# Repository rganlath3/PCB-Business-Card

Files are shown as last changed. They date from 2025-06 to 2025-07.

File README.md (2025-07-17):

# PCB Business Card
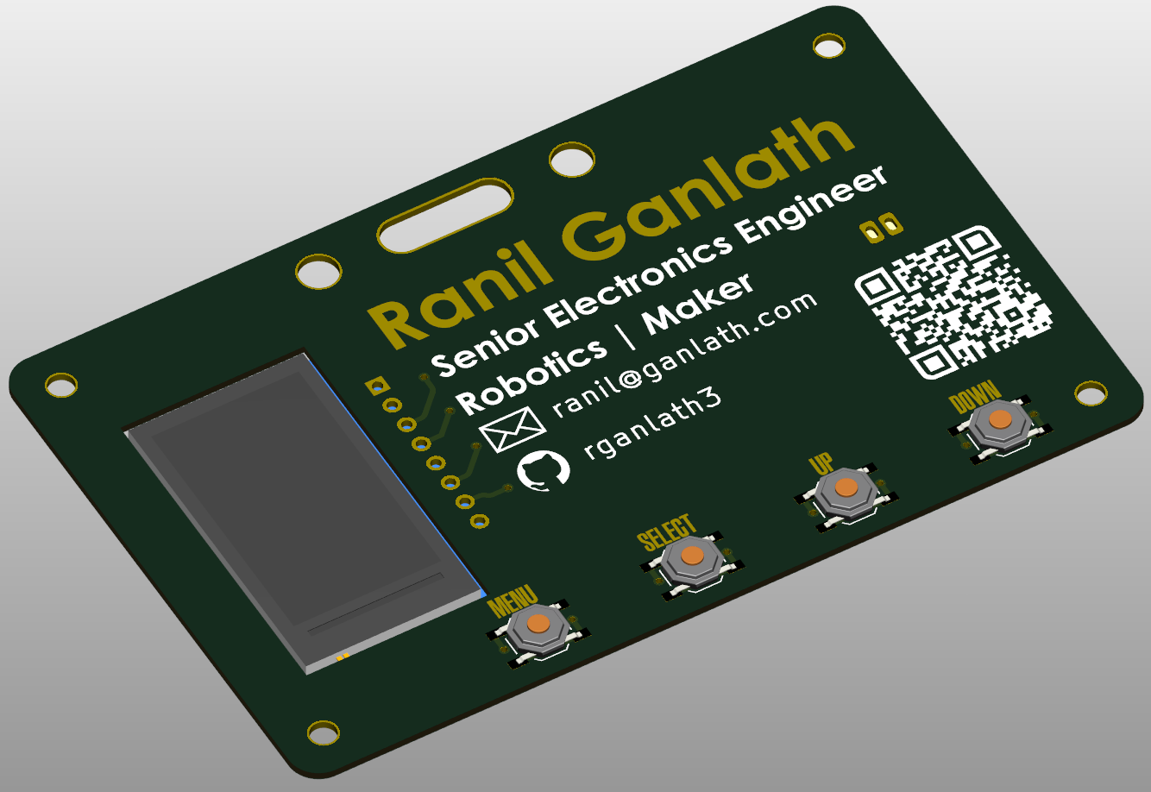
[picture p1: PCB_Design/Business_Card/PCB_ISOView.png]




[]()

<!-- ABOUT -->
## About The Project
A business card with embedded IPS display, SMD pushbuttons, and a XIAO nRF5240 Sense designed to run off a slim LiPo Battery.
The goal of this PCB is to create an artistic business card for conventions, maker spaces, and other social events that stands out either assembled or unassembled for portability.

<!-- REQUIREMENTS -->
### Design Tools & Requirements

#### Software Requirements
- VS Code / Arduino (Programming IDE)
- Autodesk Fusion360 (Free CAD Software)
- KiCAD 9.0 (Open Source PCB Design Software)
- Ultimaker Cura (Free 3D Slicing Software)
- QR Code Generator

#### Bill of Materials
- Custom PCBs
- MCU: XIAO nRF5240 Sense
- Low Profile SMD Momentary Pushbutton: TL3342
- LIPO Connector
- LIPO Battery
- 1.14" 135x240 RGB IPS LCD SPI Display with ST7789V driver IC.

<!-- POWER -->
### Component Power Draw
- XIAO nRF5240 Sense:
- IPS Display:
- Total:
- With Safety Factor (x1.25):
- Recommended Lipo: 
- Estimated Battery Life:

<!-- PCB Design -->
### PCB Design
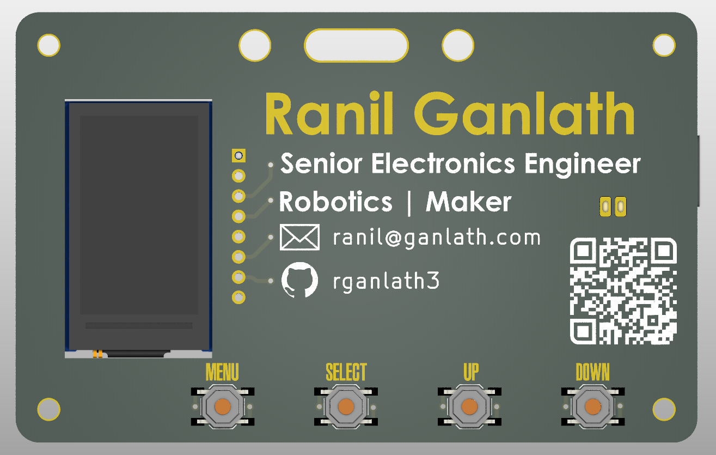
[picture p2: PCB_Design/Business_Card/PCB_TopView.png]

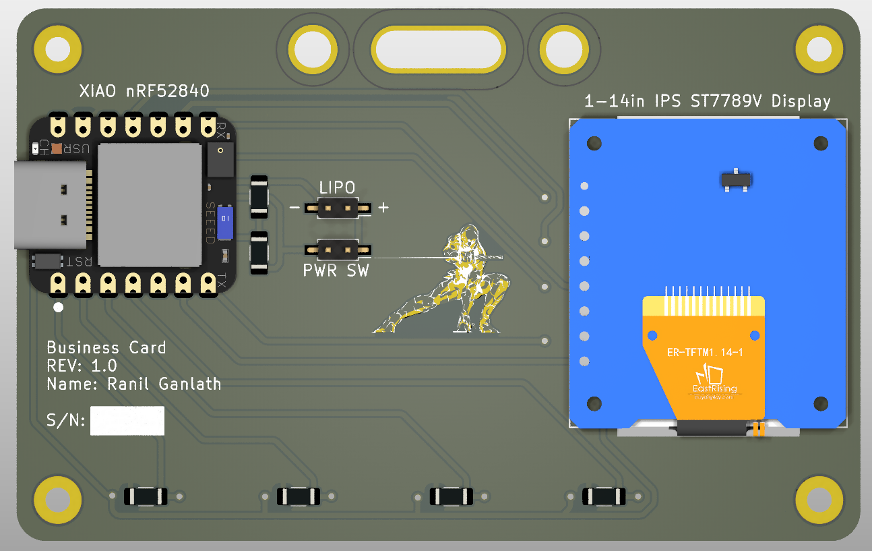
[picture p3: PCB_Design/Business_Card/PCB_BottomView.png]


This PCB is used to interface a XIAO nRF5240 Sense with the following components:
- SMD Pushbuttons
- IPS Display
- Power Source (Lipo Battery)

I did some research on artistic designs and found people using soldermask as a visual aesthetic. When the board is finished with ENIG, it produces a protected and nice gold finish.
For the board thickness I went with 0.8mm. (Typical board is 1.6mm). For future revisions, I may make the board even thinner.
The end goal is not use a breakout board and to simply have the nRF5240 or another board like the ESP32-S3 bare chip used along with battery charging and microphone circuits to reduce the physical space taken up. 

<!-- Software -->
### Software Design
With 4x buttons available along with a microphone input, a variety of things can be displayed on the screen.
I wanted to incorporate a menu system so I can toggle between different modes such as a battery readout display, static image display such as for a QR code, a looping GIF display, a sound reactive display mode, and a control mode to set ambient audio input levels. The limitation of all of this is the amount of flash memory on the XIAO nRF5240. For future revisions, I can incorporate a microSD card.

#### Menu Display
- Call
    - Snake
    - Campbell
    - Naomi
    - Miller
    - Liquid
    - Otacon
    - Sniper Wolf
    - Meryl
    - Mei Ling
    - Nastasha
    - Dt
- Incoming Call
- Animated
    - Snake
    - Campbell
    - Naomi
    - Miller
    - Otacon
    - Sniper Wolf
    - Meryl
    - Mei Ling
    - Nastasha
- Settings
    - Brightness
    - Restart System
- QR
    - QR code for this project
    - QR code for my LinkedIn
    - QR code for my github
- Games
    - TBD
- Sleep

#### Battery Readout Display
TBD

#### Static Image Display
TBD

#### Looping GIF Display
TBD

#### Sound Reactive Display
TBD

#### Ambient Audio Config Display
TBD

#### Game Display
TBD

<!-- CONTRIBUTING -->
## Contributing & Donations

Any donation helps to support parts for future open source projects!
[Buy Me a Coffee ☕](https://www.buymeacoffee.com/rganlath)

Contributions are what make the open source community such an amazing place to learn, inspire, and create. Any contributions you make are **greatly appreciated**.

If you have a suggestion that would make this better, please fork the repo and create a pull request. You can also simply open an issue with the tag "enhancement".
Don't forget to give the project a star! Thanks again!

<!-- LICENSE -->
## License
The contents of this project itself is licensed under CERN-OHL-S-2.0 and the underlying source code is licensed under GNU GPLv3. Both of these licenses require attribution.

<!-- SPECIAL THANKS -->
## Special Thanks
Special thanks to the following creators' github repos for inspiration and techniques used in this project:
- River Wang: https://github.com/urfdvw/cardtuber
- Anythony Kouttron: https://salvagedcircuitry.com/pcb-business-card.html

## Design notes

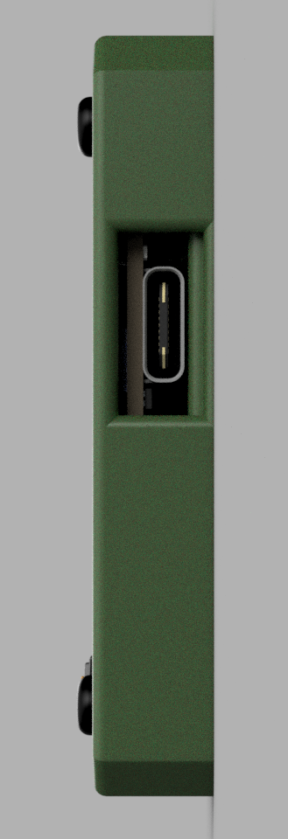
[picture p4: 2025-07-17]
Visual_Assetts/Side View.png

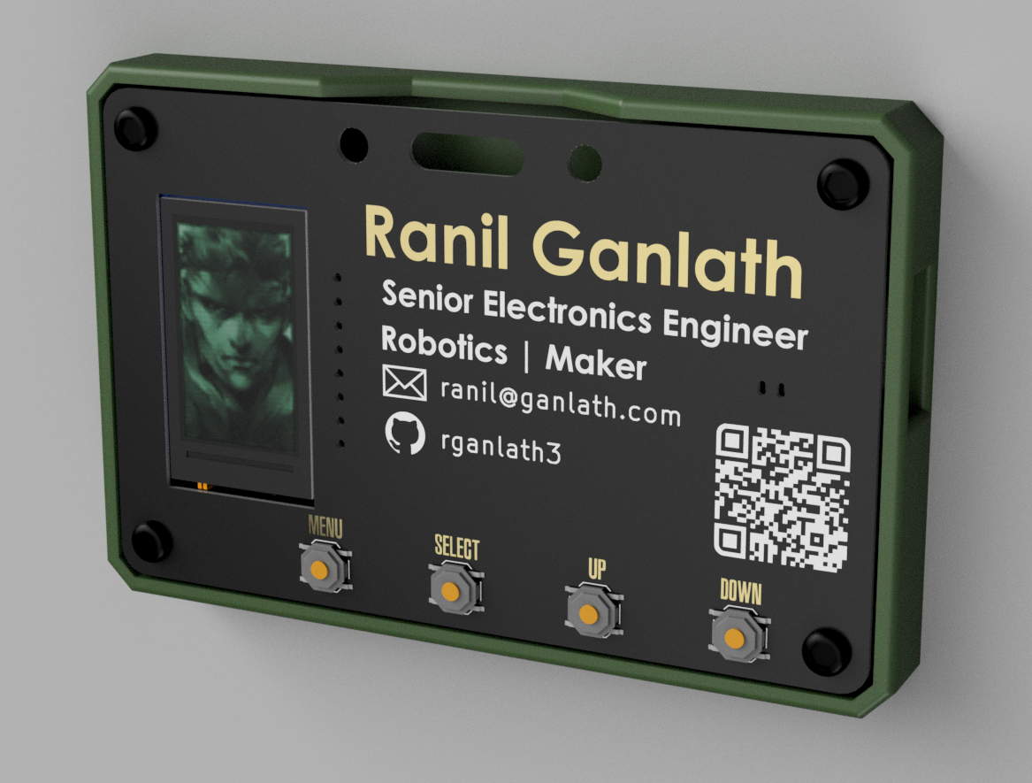
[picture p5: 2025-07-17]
Visual_Assetts/MK1 Render Iso View.png

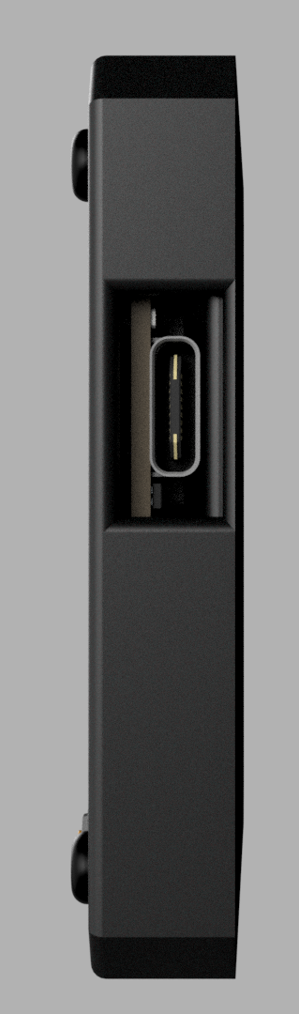
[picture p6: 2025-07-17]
Visual_Assetts/Side View2.png

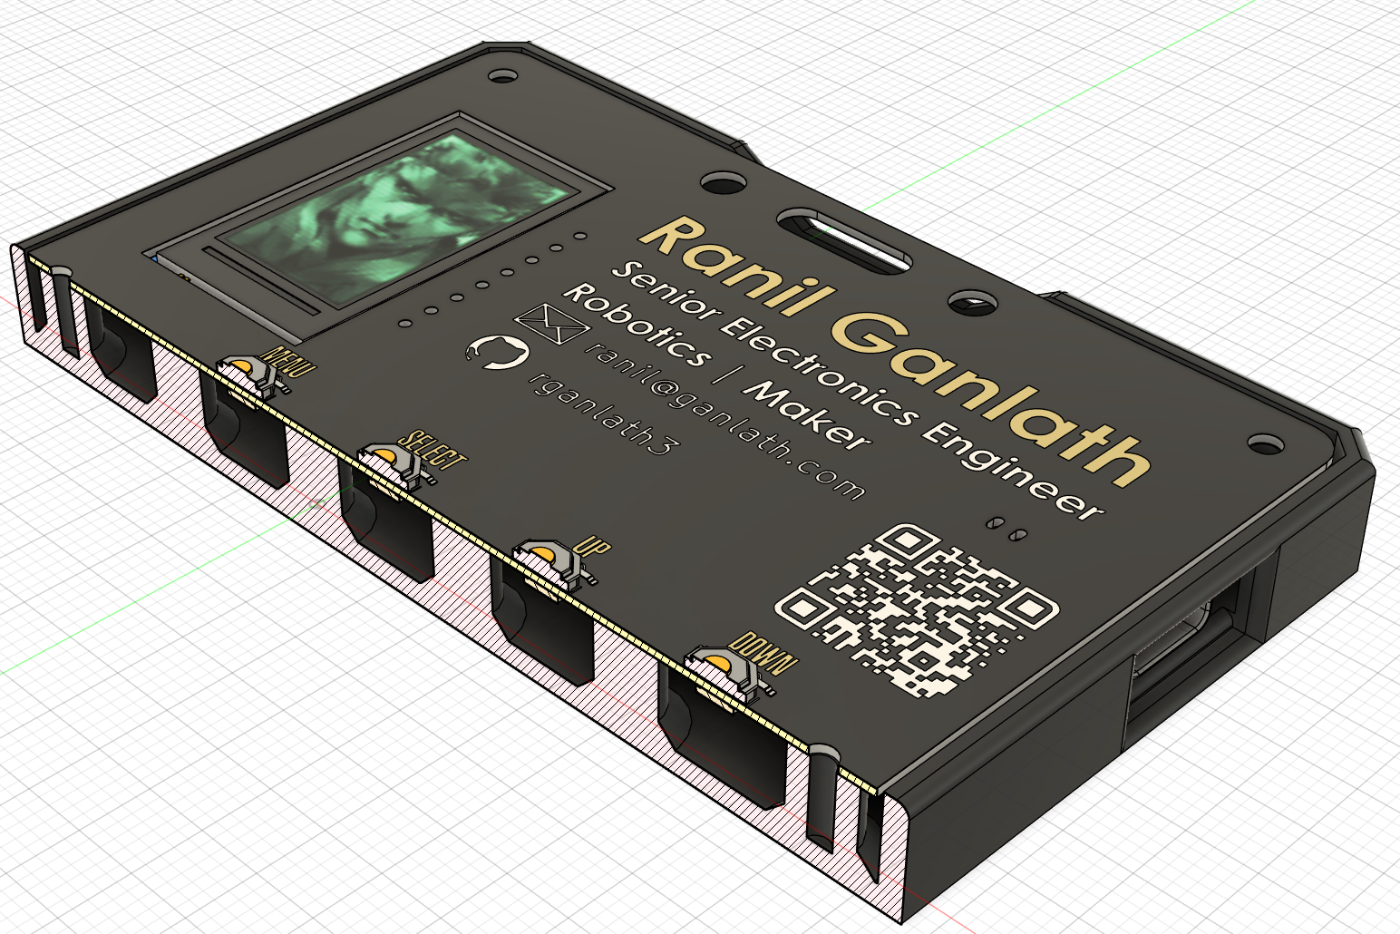
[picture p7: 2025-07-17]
Visual_Assetts/SectionalAnalysis.png

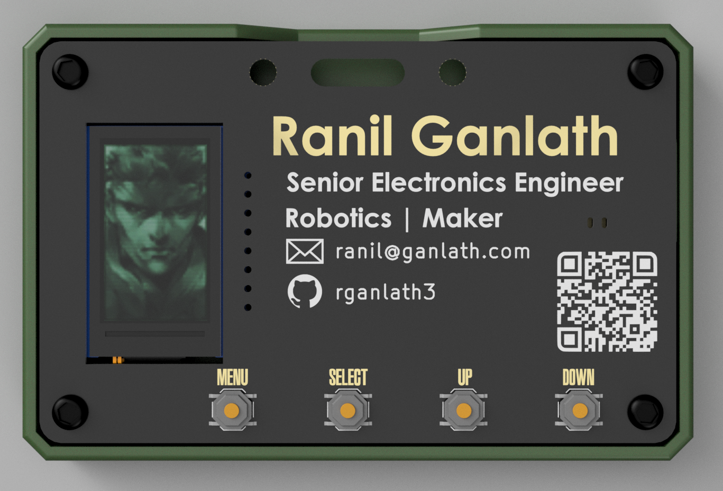
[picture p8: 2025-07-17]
Visual_Assetts/MK1 Render Front View.png

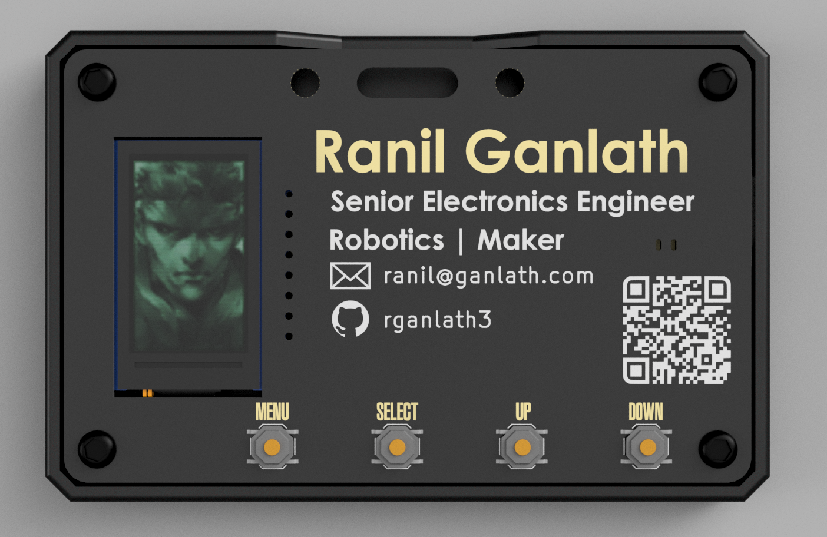
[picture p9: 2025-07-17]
Visual_Assetts/MK1 Render Front View2.png

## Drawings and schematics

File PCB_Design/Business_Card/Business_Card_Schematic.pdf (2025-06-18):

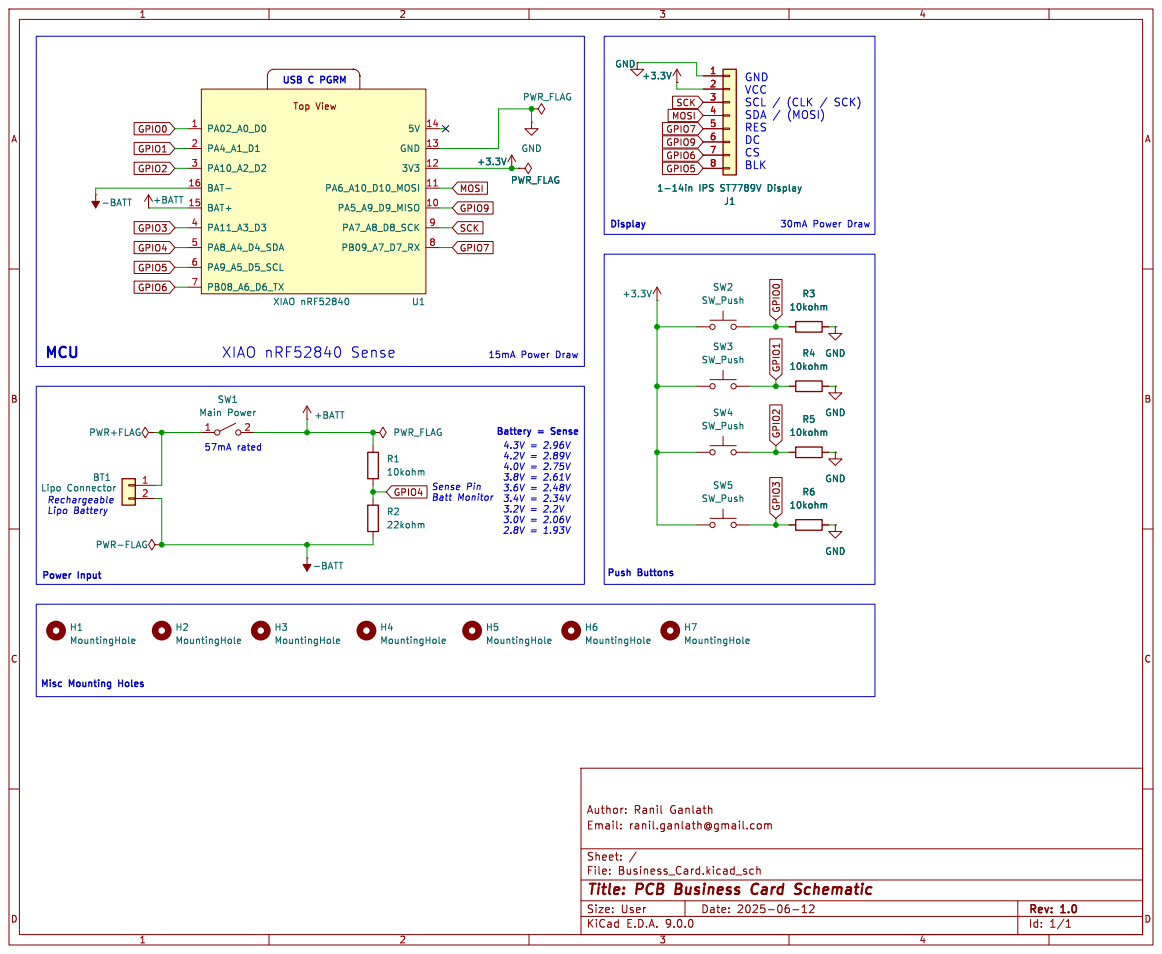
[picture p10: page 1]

VCC
SCL / (CLK / SCK) SDA / (MOSI) RES DC

Id: 1/1 Title: PCB Business Card Schematic

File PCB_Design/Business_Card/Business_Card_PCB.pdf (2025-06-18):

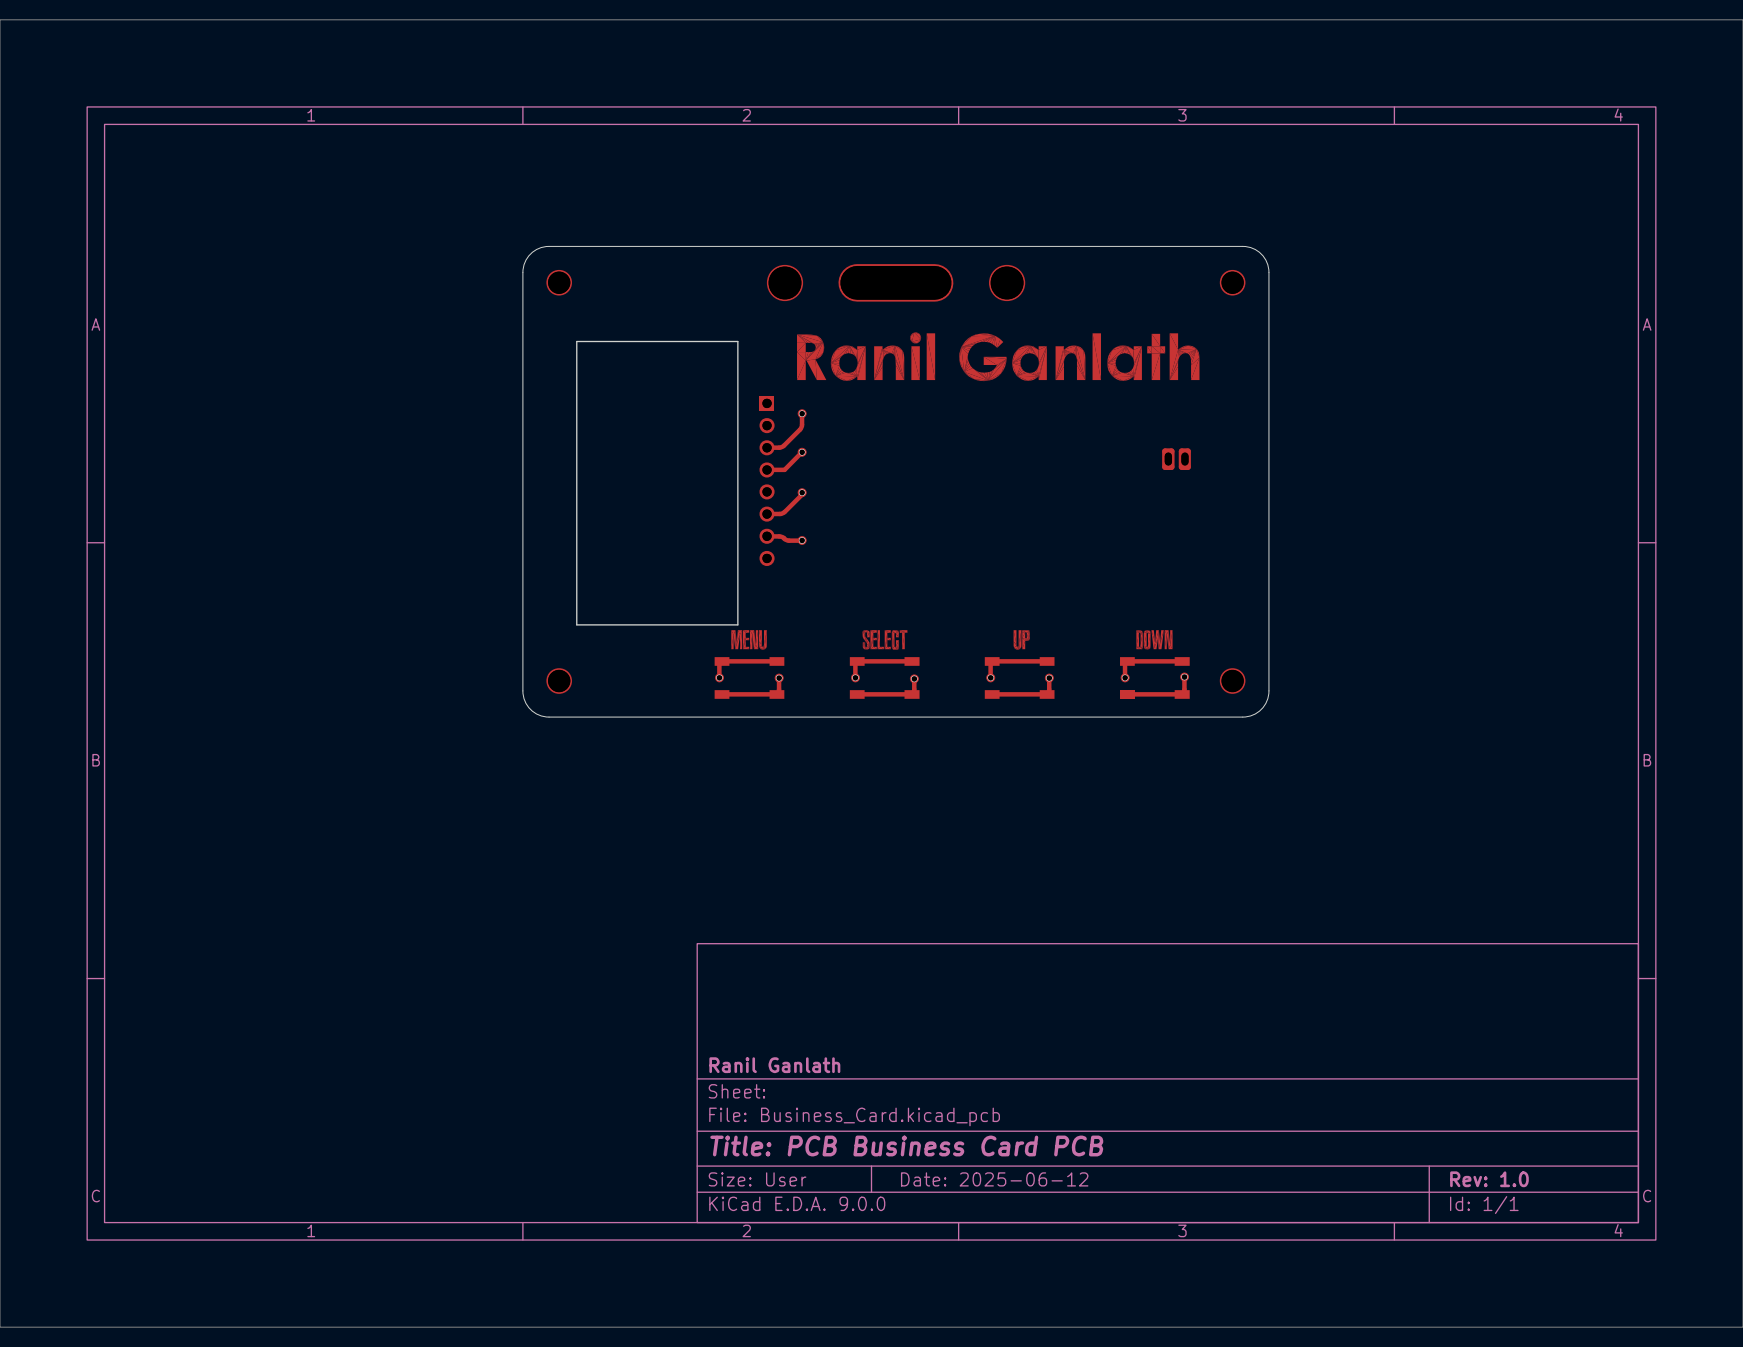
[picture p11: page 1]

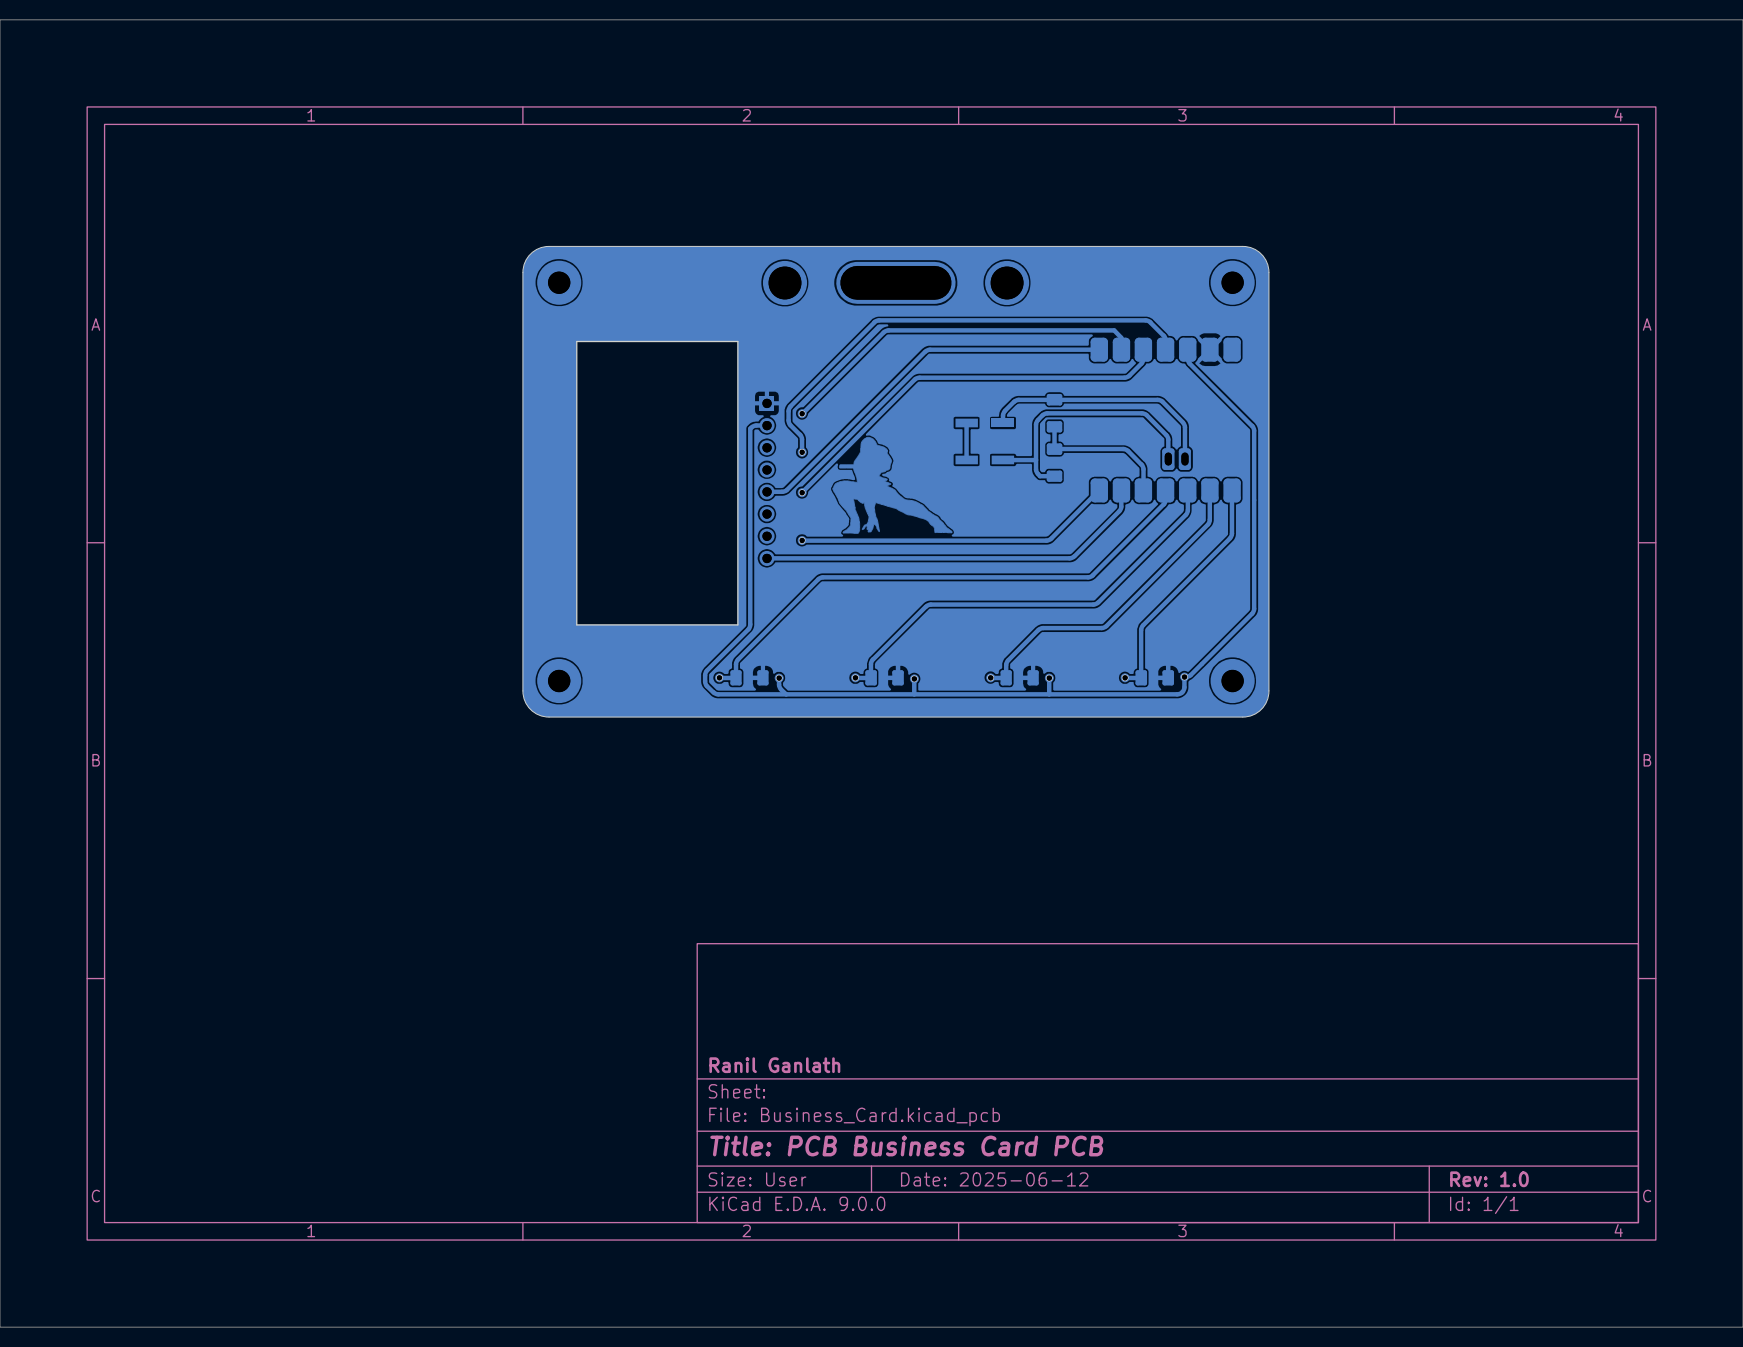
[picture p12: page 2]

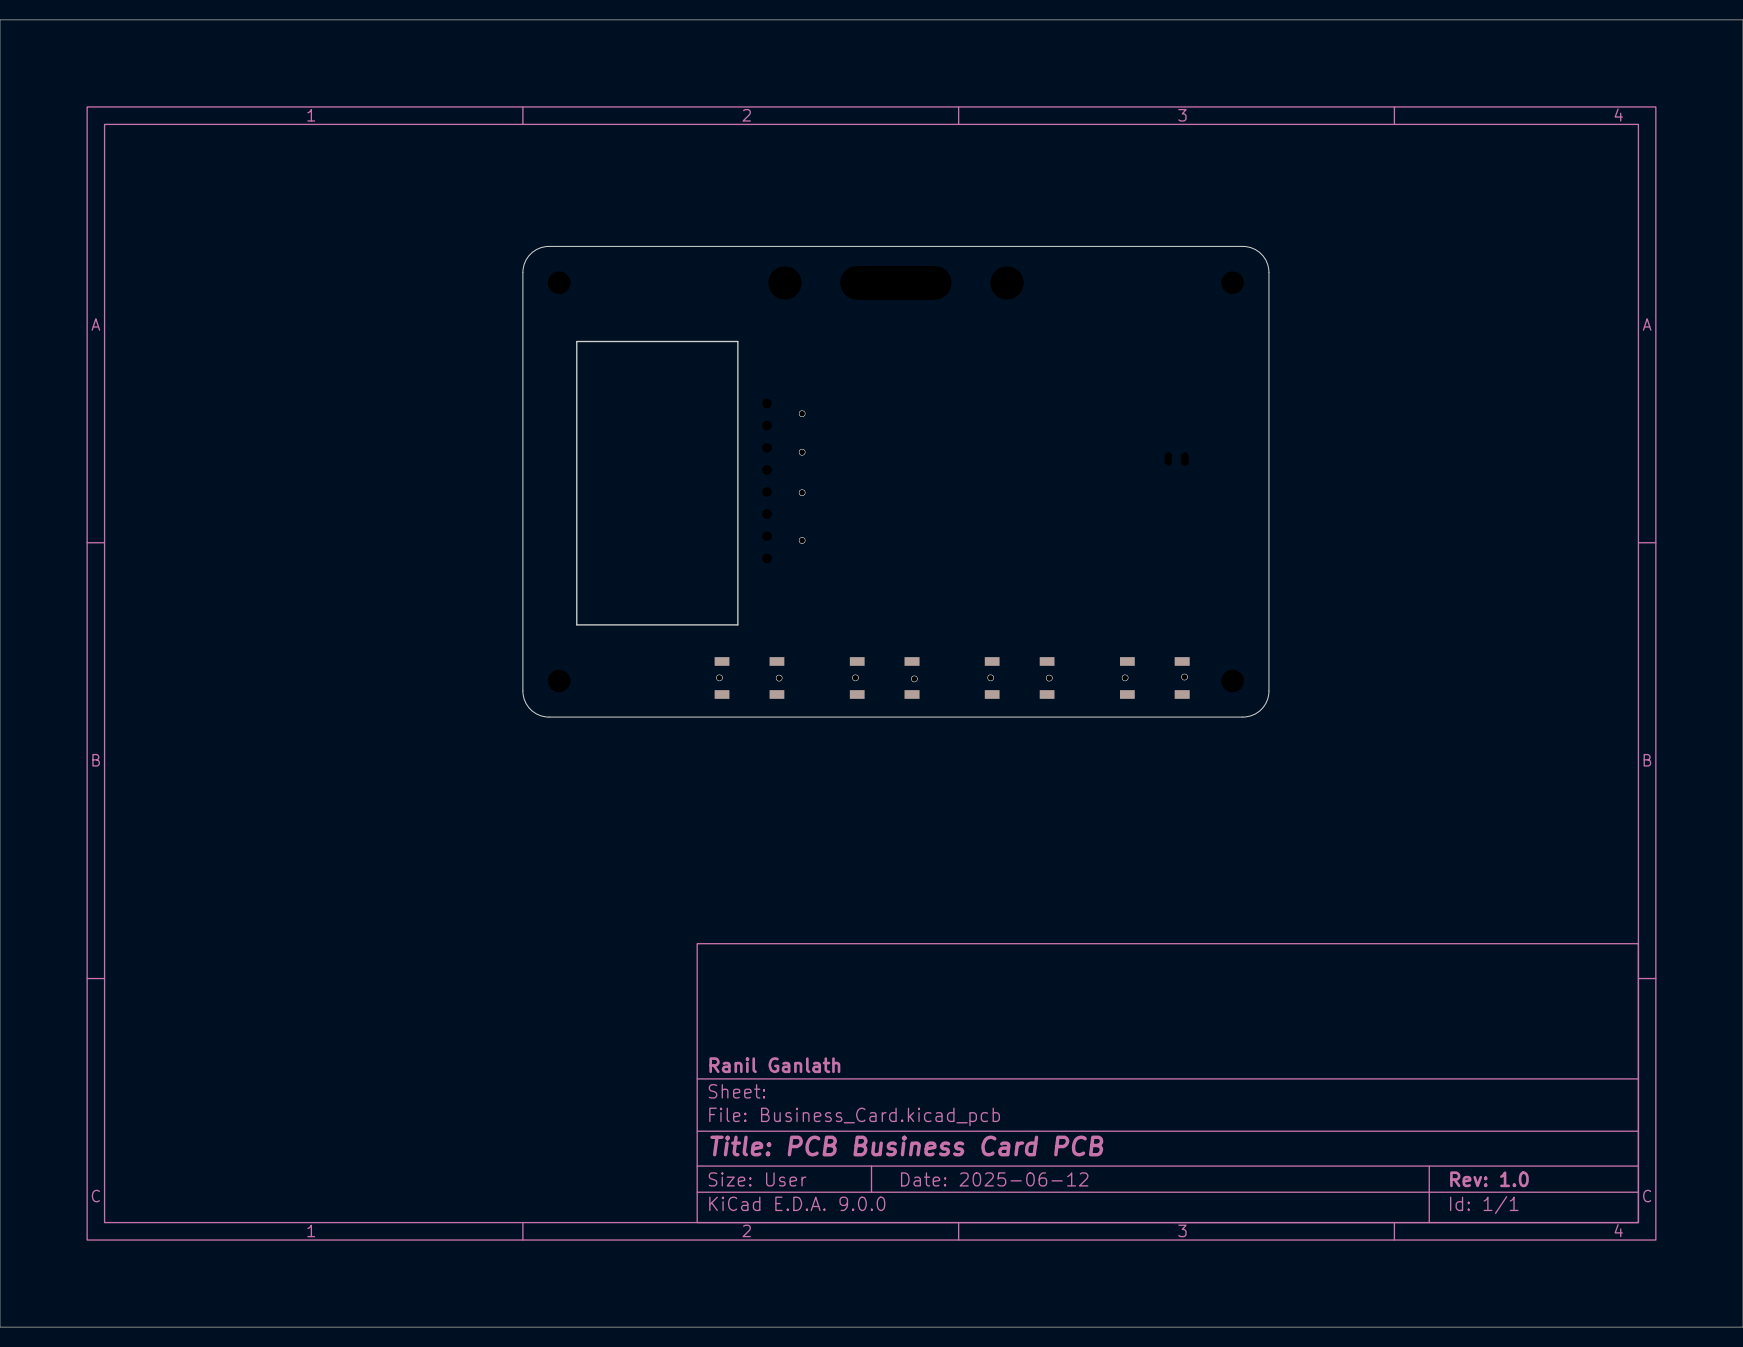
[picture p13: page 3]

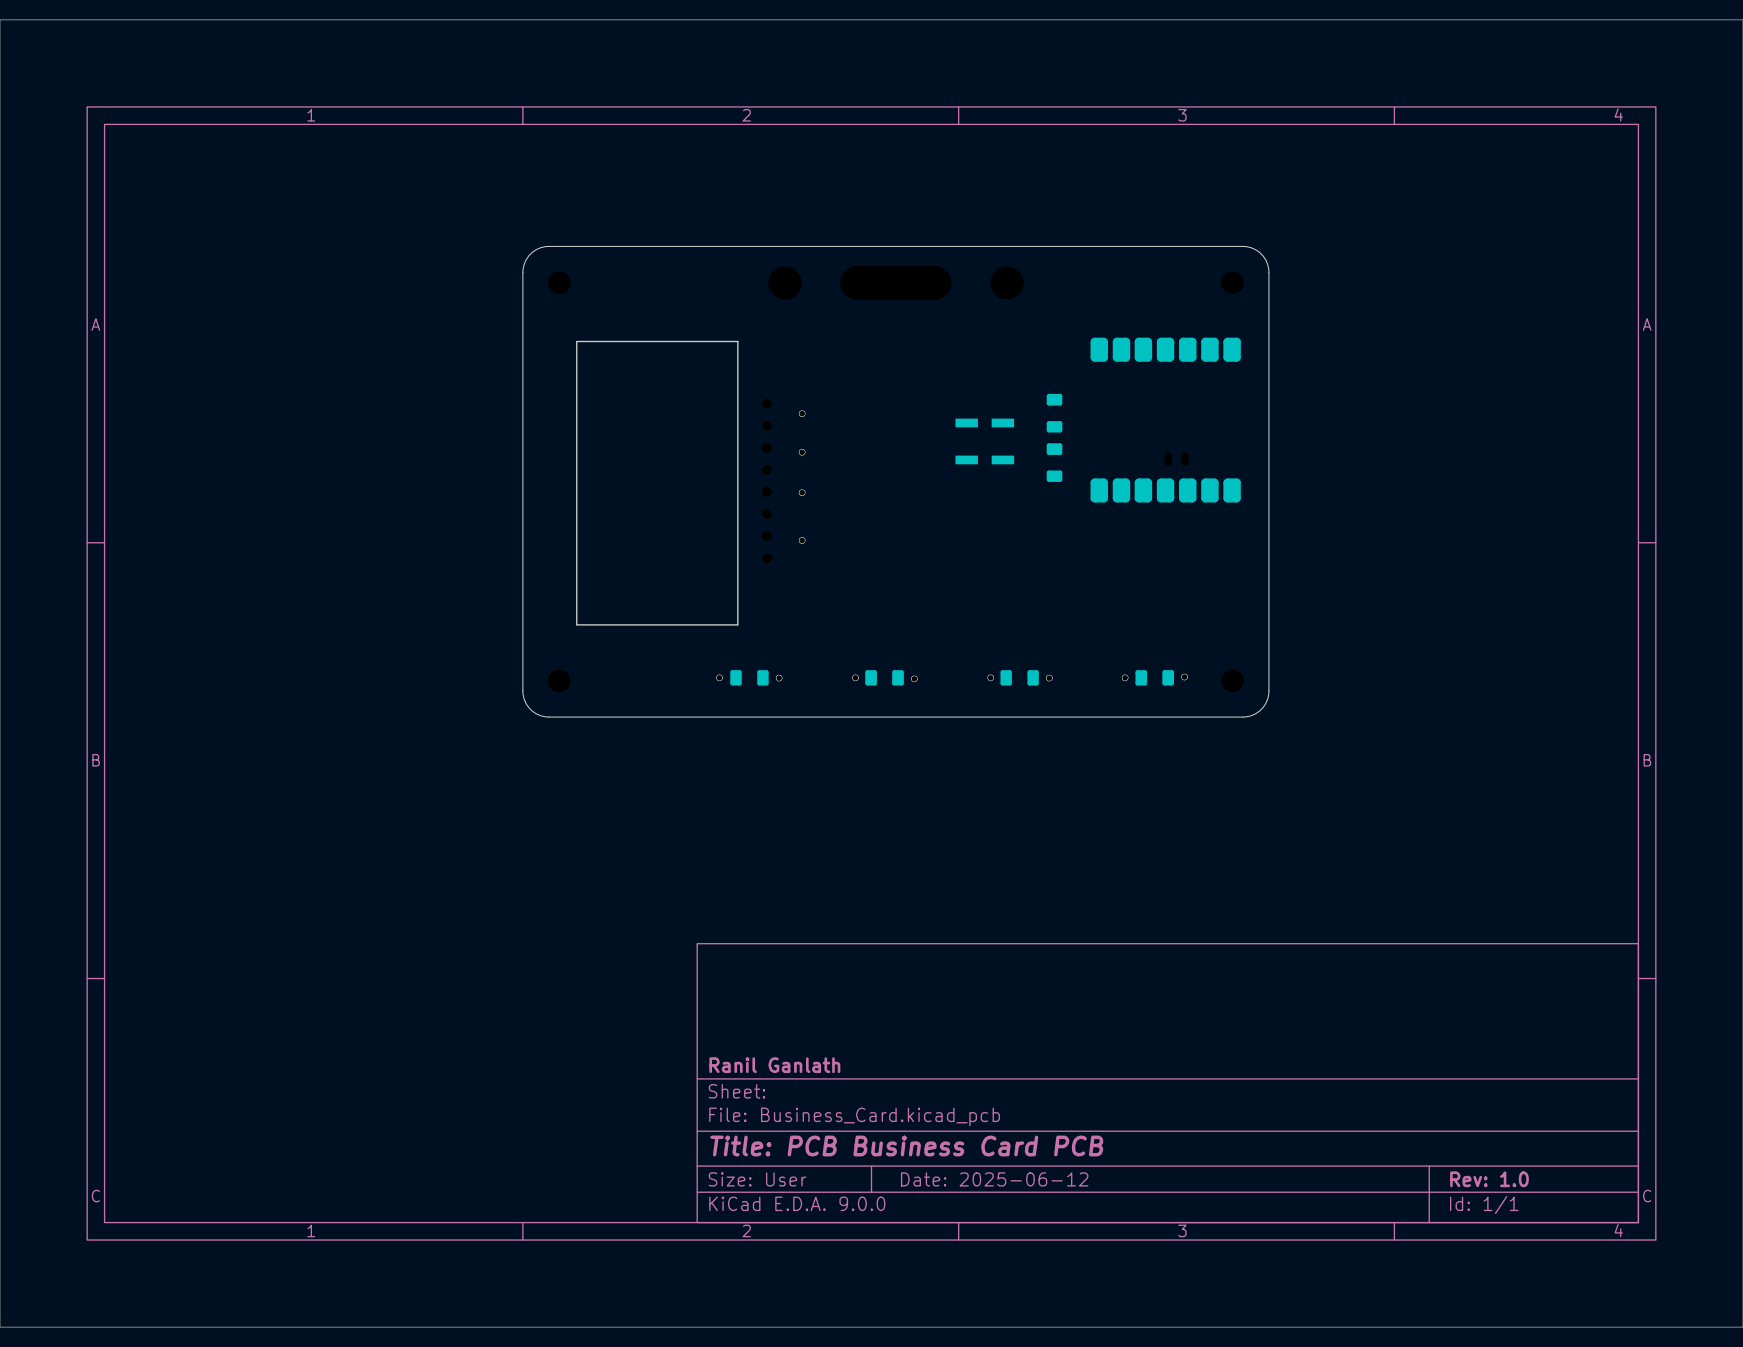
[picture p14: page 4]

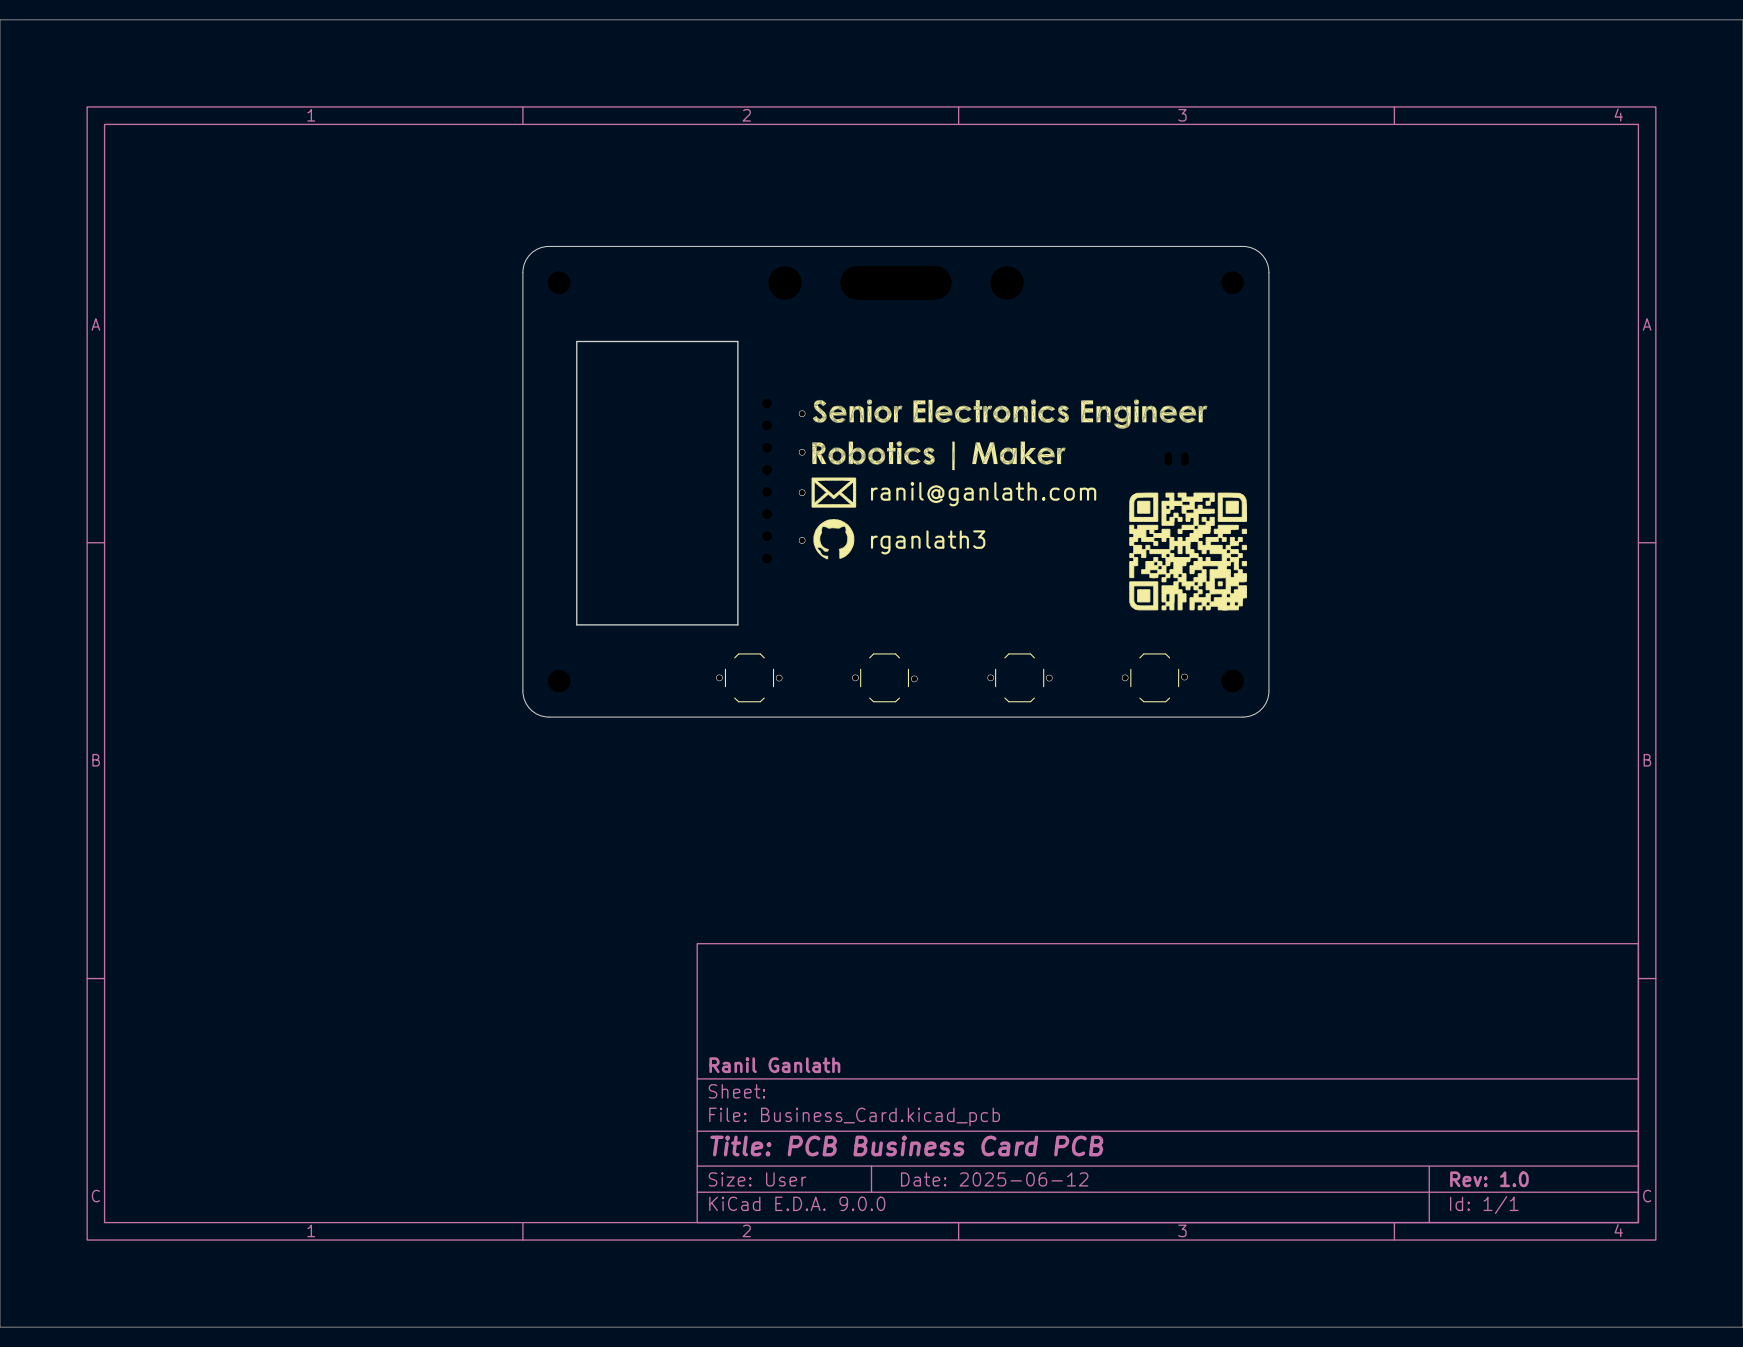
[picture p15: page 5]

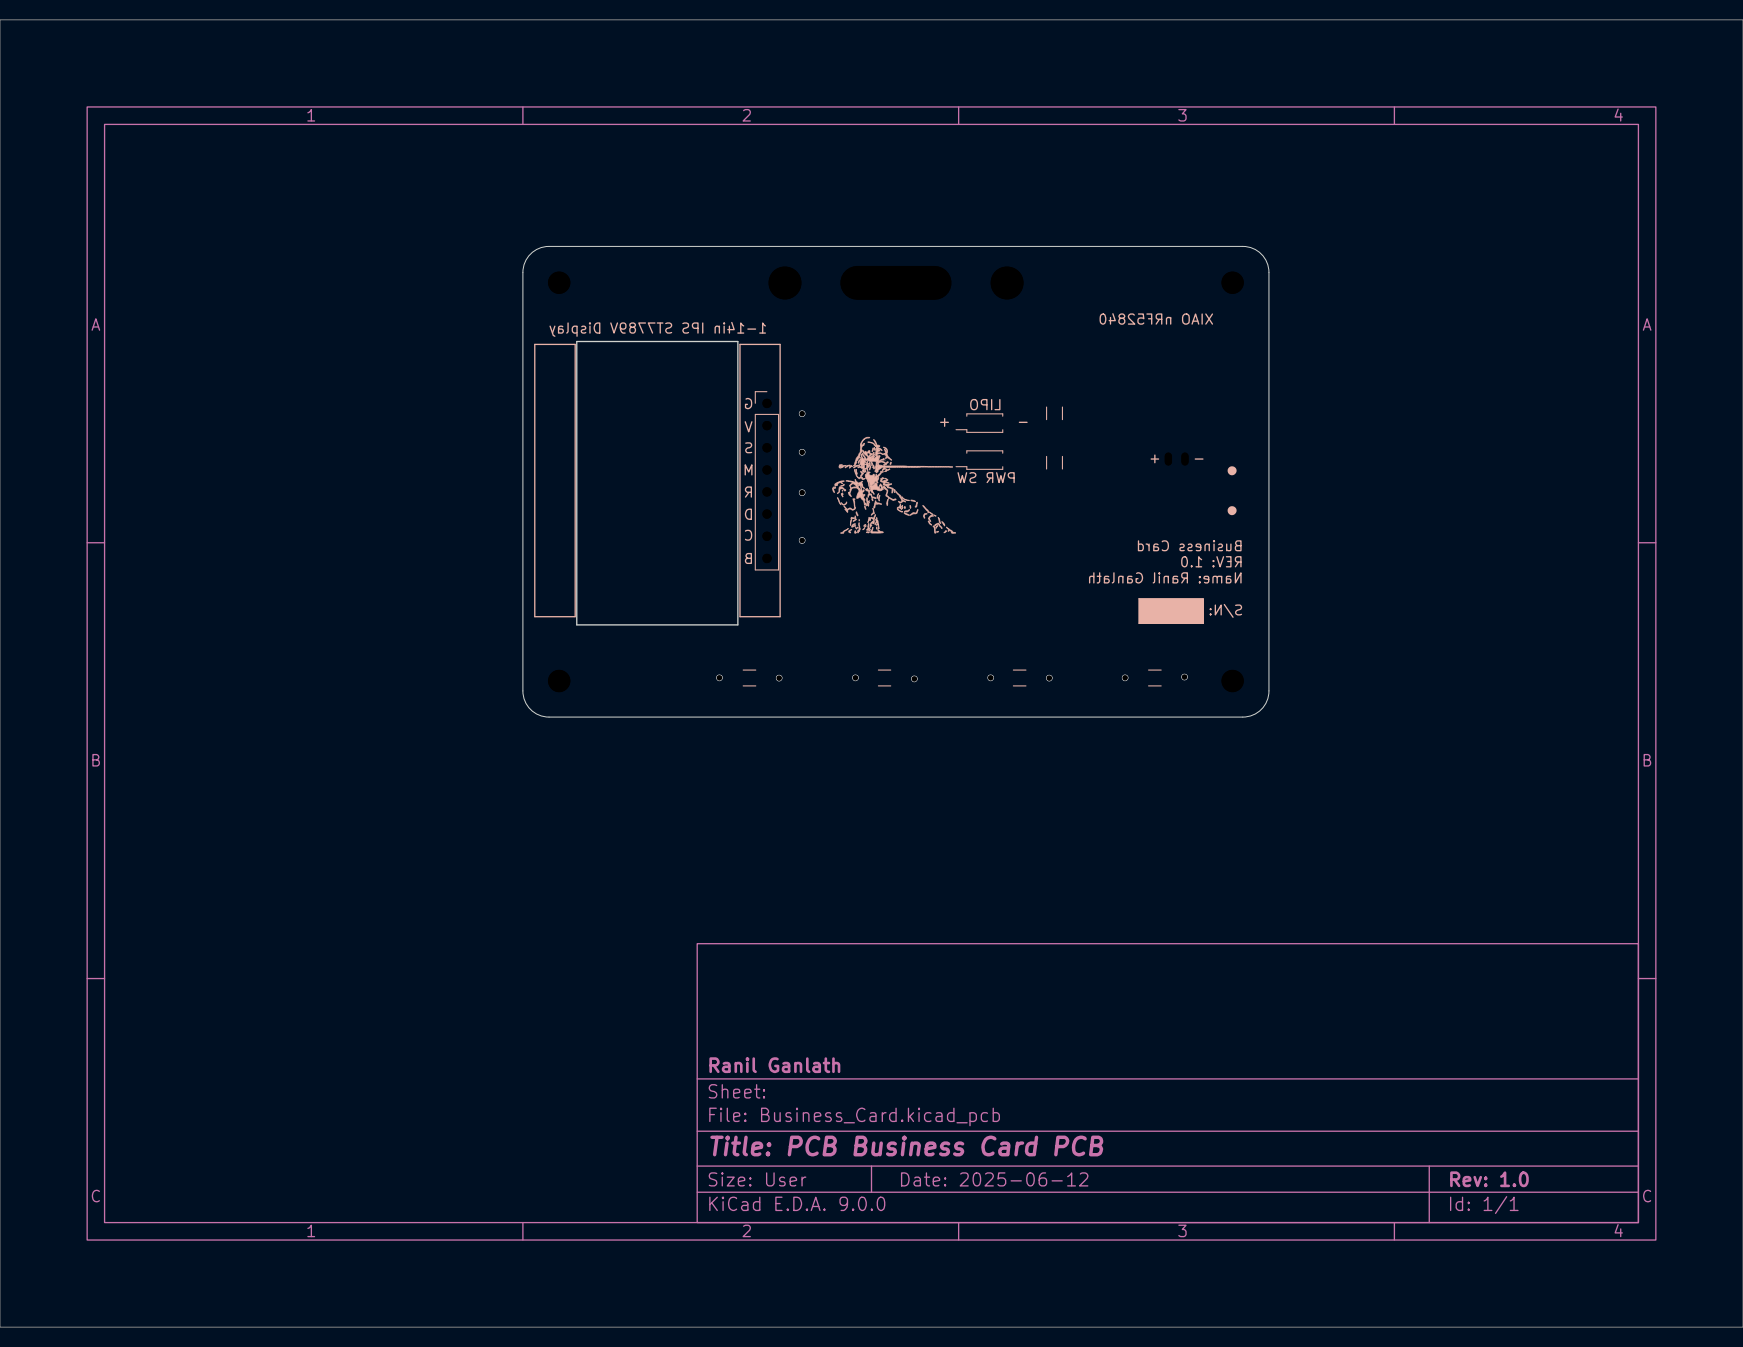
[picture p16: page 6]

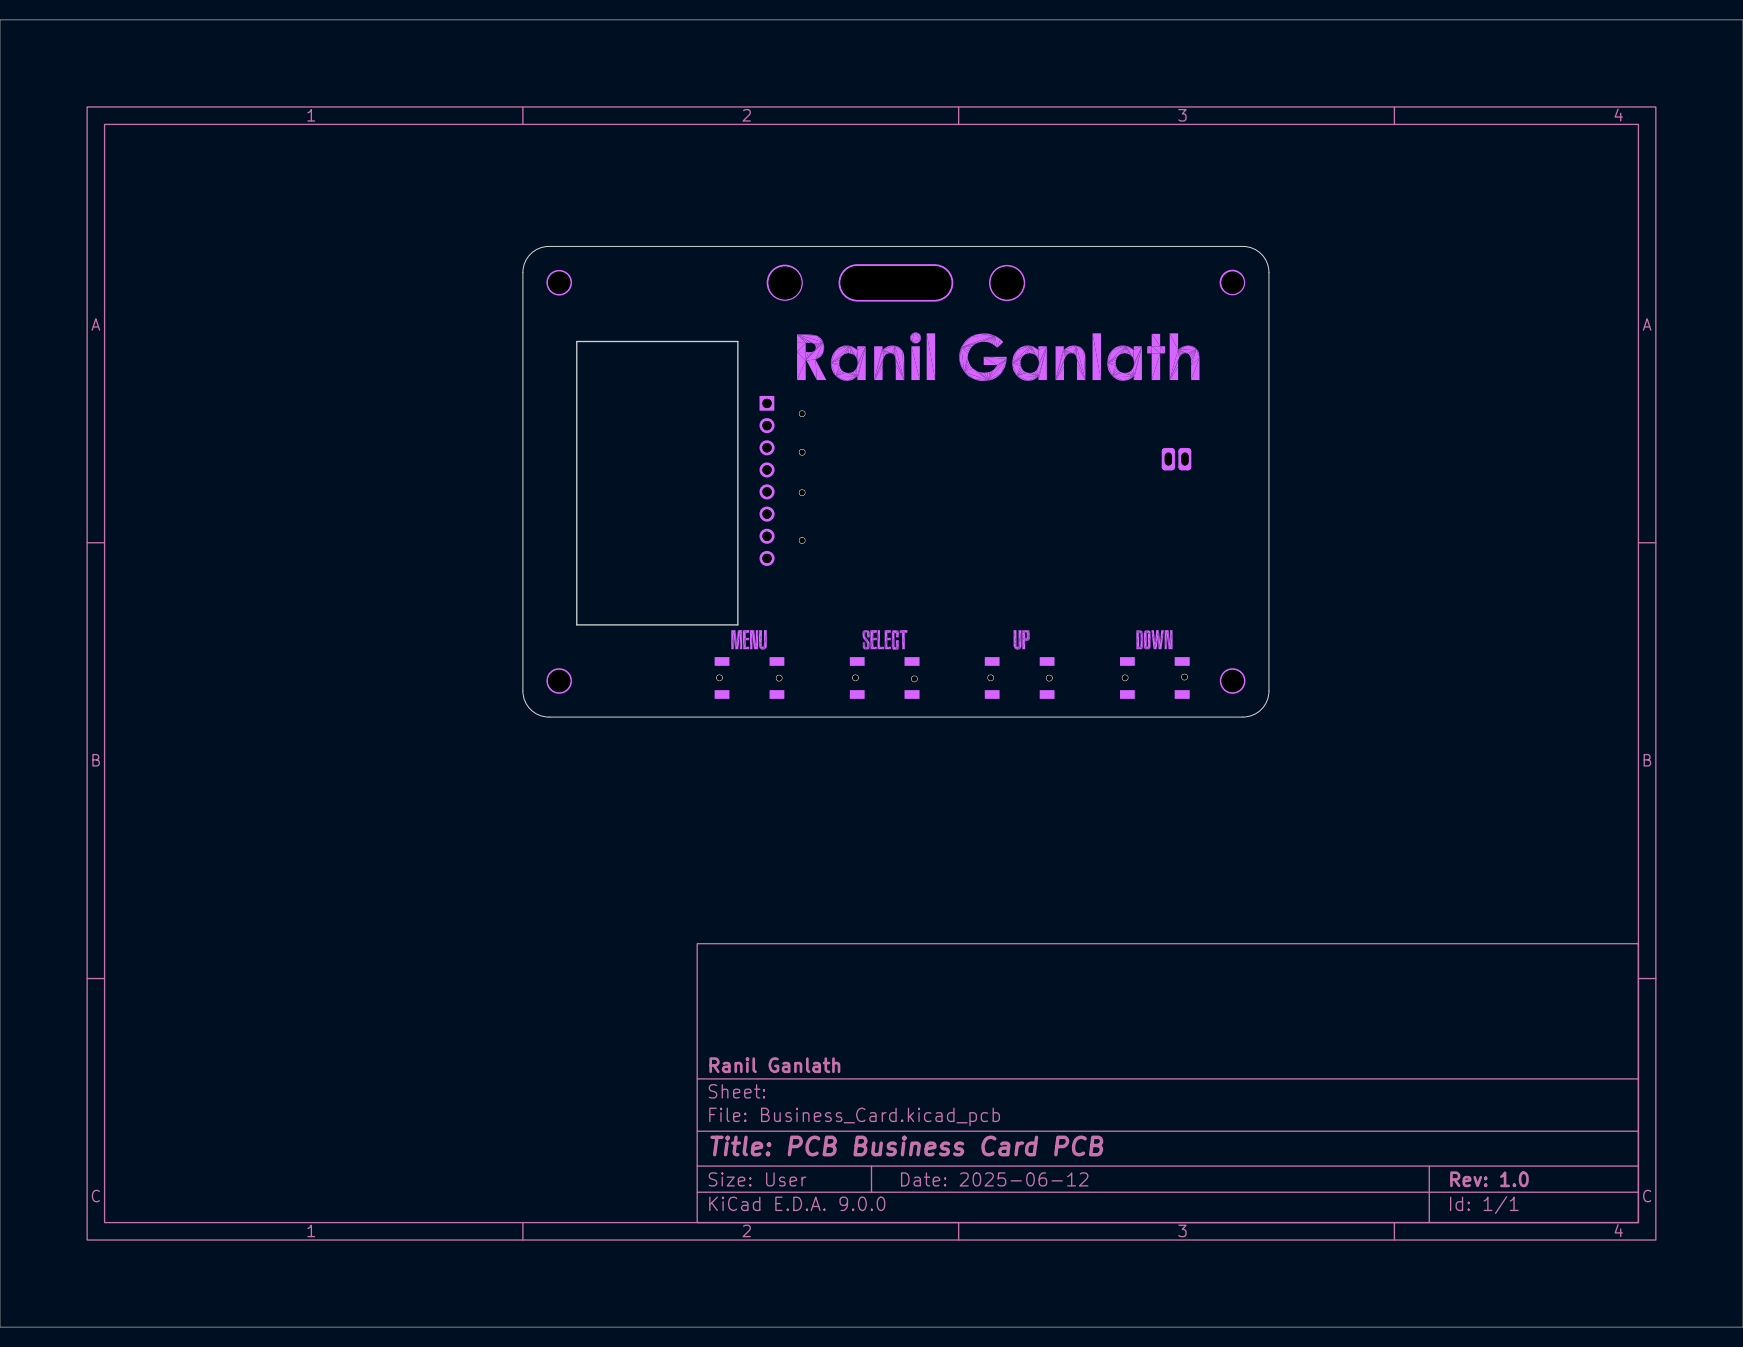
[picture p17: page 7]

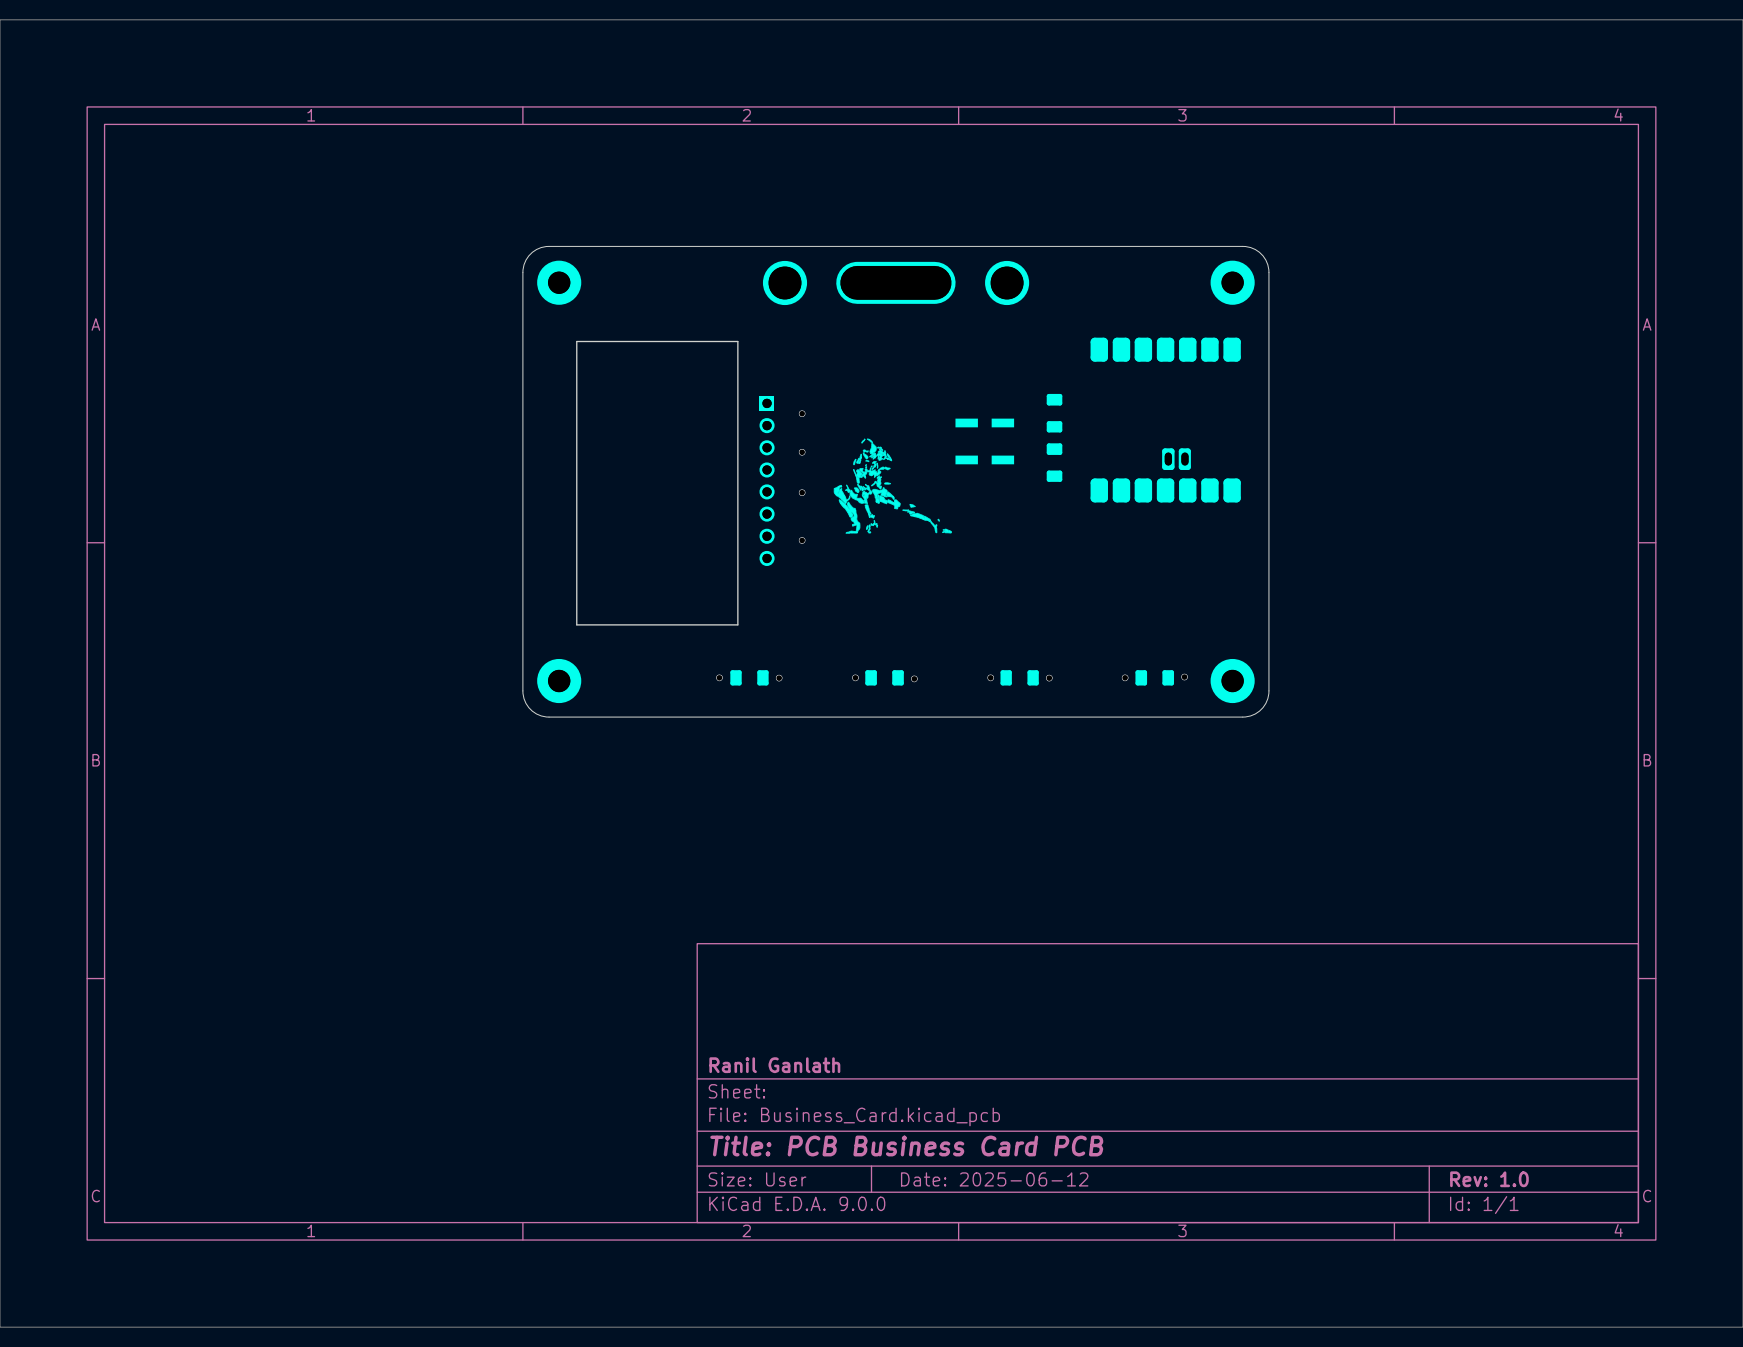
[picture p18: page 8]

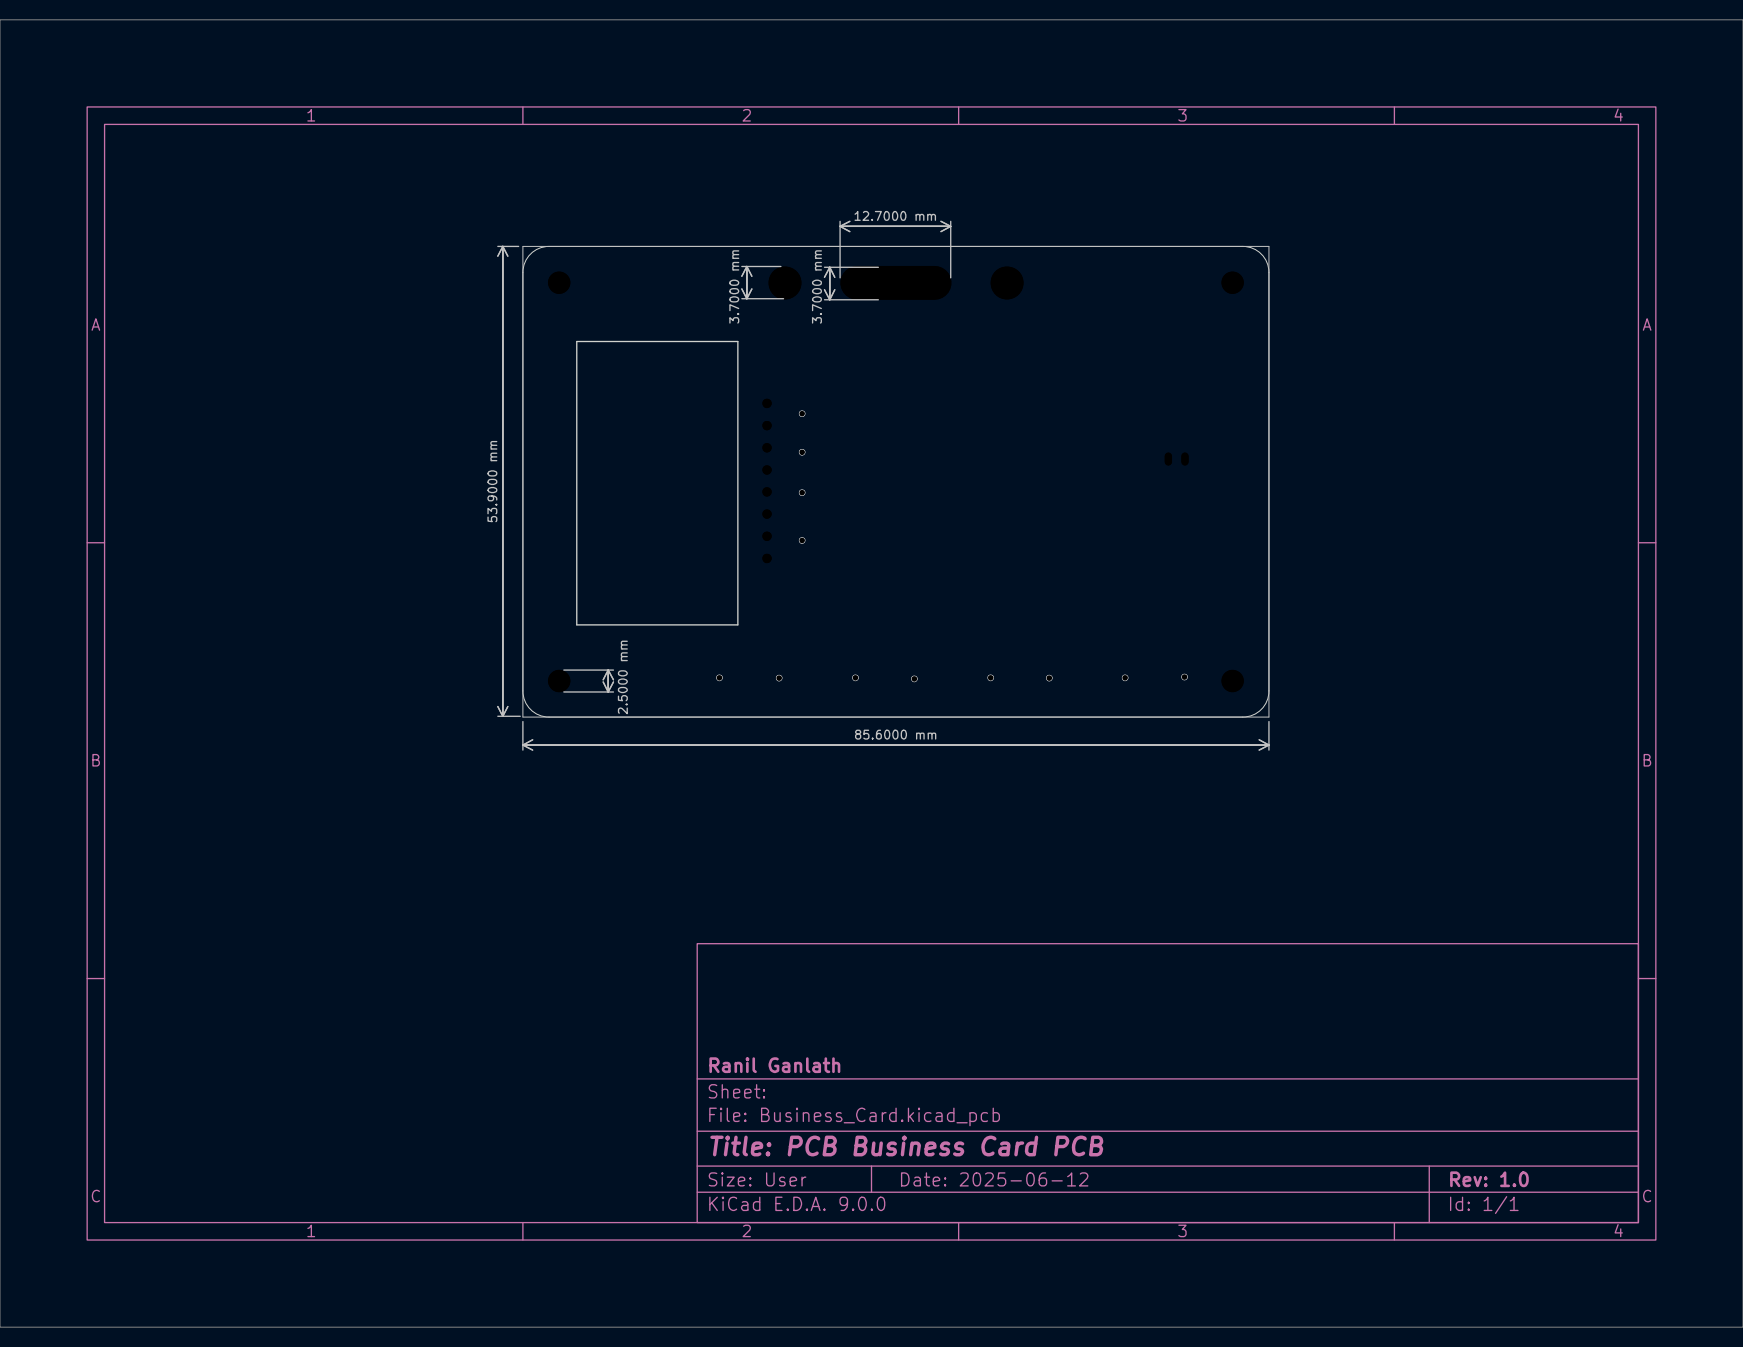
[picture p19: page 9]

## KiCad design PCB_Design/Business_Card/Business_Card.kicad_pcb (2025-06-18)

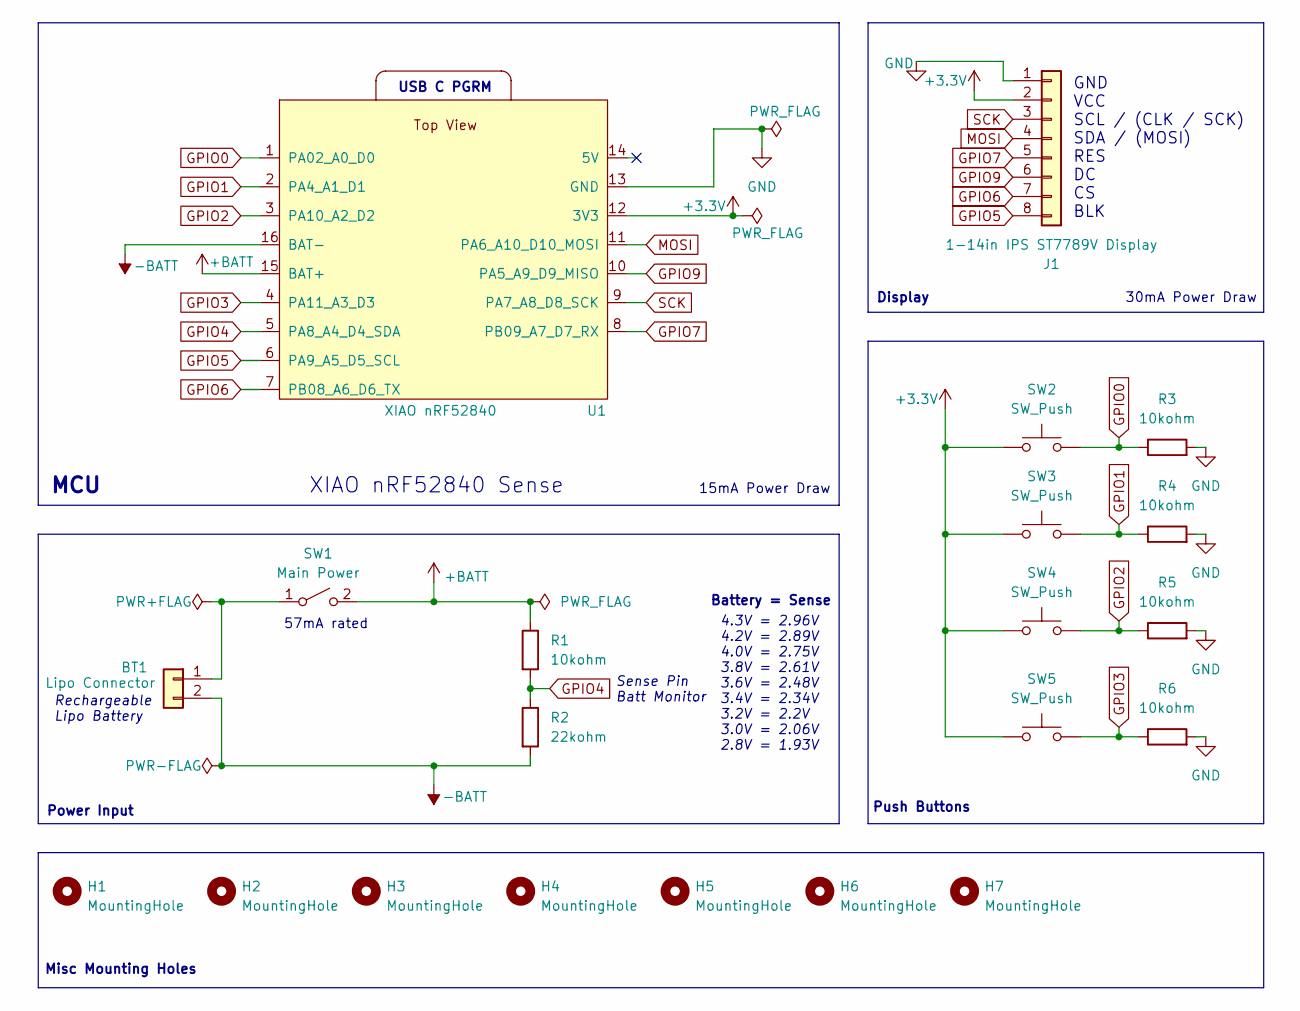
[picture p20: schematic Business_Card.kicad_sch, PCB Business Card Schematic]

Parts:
BT1: Lipo Connector; PinHeader_2x01_P2.00mm_Vertical_SMD
H1, H2, H3, H4: MountingHole; MountingHole_2.5mm_Pad_TopOnly
H5, H7: MountingHole; MountingHole_3.7mm_Core
H6: MountingHole; MountingHole_3.7mm_Lanyard_Core
J1: 1-14in IPS ST7789V Display; 1-14in_IPS_ST7789V_Display
R1, R3, R4, R5, R6: 10kohm; R_1206_3216Metric_Pad1.30x1.75mm_HandSolder
R2: 22kohm; R_1206_3216Metric_Pad1.30x1.75mm_HandSolder
SW1: Main Power; PinHeader_2x01_P2.00mm_Vertical_SMD
SW2, SW3, SW4, SW5: SW_Push; SW_SPST_TL3342
U1: XIAO nRF52840; XIAO-nRF52840-SMD_Revised

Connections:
+3.3V: J1.2, SW2.1, SW3.1, SW4.1, SW5.1, U1.12 (3V3)
+BATT: R1.1, SW1.2 (B), U1.15 (BAT+)
-BATT: BT1.2, R2.2, U1.16 (BAT-)
GND: J1.1, R3.2, R4.2, R5.2, R6.2, U1.13 (GND)
GPIO0: R3.1, SW2.2, U1.1 (PA02_A0_D0)
GPIO1: R4.1, SW3.2, U1.2 (PA4_A1_D1)
GPIO2: R5.1, SW4.2, U1.3 (PA10_A2_D2)
GPIO3: R6.1, SW5.2, U1.4 (PA11_A3_D3)
GPIO4: R1.2, R2.1, U1.5 (PA8_A4_D4_SDA)
GPIO5: J1.8, U1.6 (PA9_A5_D5_SCL)
GPIO6: J1.7, U1.7 (PB08_A6_D6_TX)
GPIO7: J1.5, U1.8 (PB09_A7_D7_RX)
GPIO9: J1.6, U1.10 (PA5_A9_D9_MISO)
MOSI: J1.4, U1.11 (PA6_A10_D10_MOSI)
unnamed: BT1.1, SW1.1 (A)
SCK: J1.3, U1.9 (PA7_A8_D8_SCK)

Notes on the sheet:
MCU
Battery = Sense
Power Input
30mA Power Draw
57mA rated
Push Buttons
XIAO nRF52840 Sense
Misc Mounting Holes
Sense Pin Batt Monitor
GND VCC SCL / (CLK / SCK) SDA / (MOSI) RES DC CS BLK
15mA Power Draw
Rechargeable Lipo Battery
Display
USB C PGRM
4.3V = 2.96V 4.2V = 2.89V 4.0V = 2.75V 3.8V = 2.61V 3.6V = 2.48V 3.4V = 2.34V 3.2V = 2.2V 3.0V = 2.06V 2.8V = 1.93V

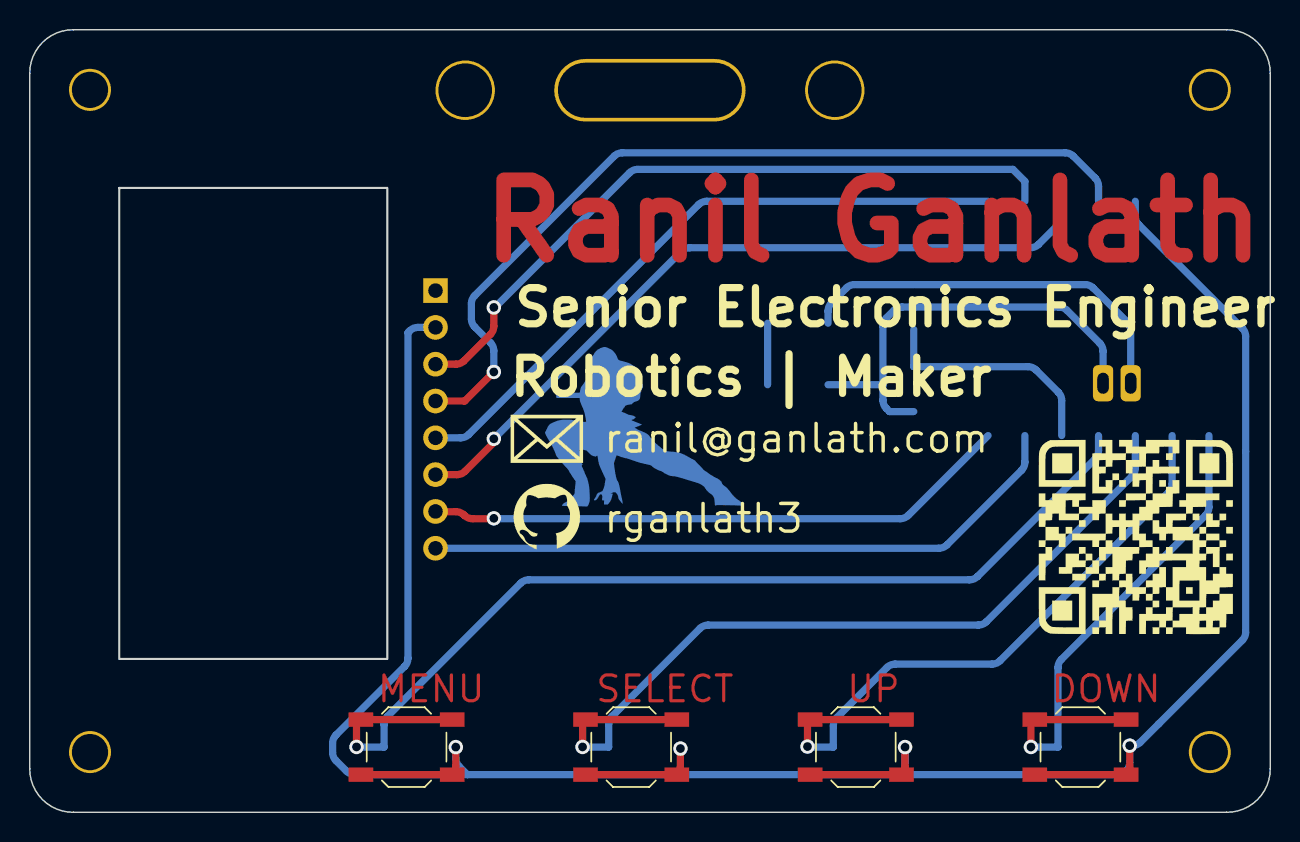
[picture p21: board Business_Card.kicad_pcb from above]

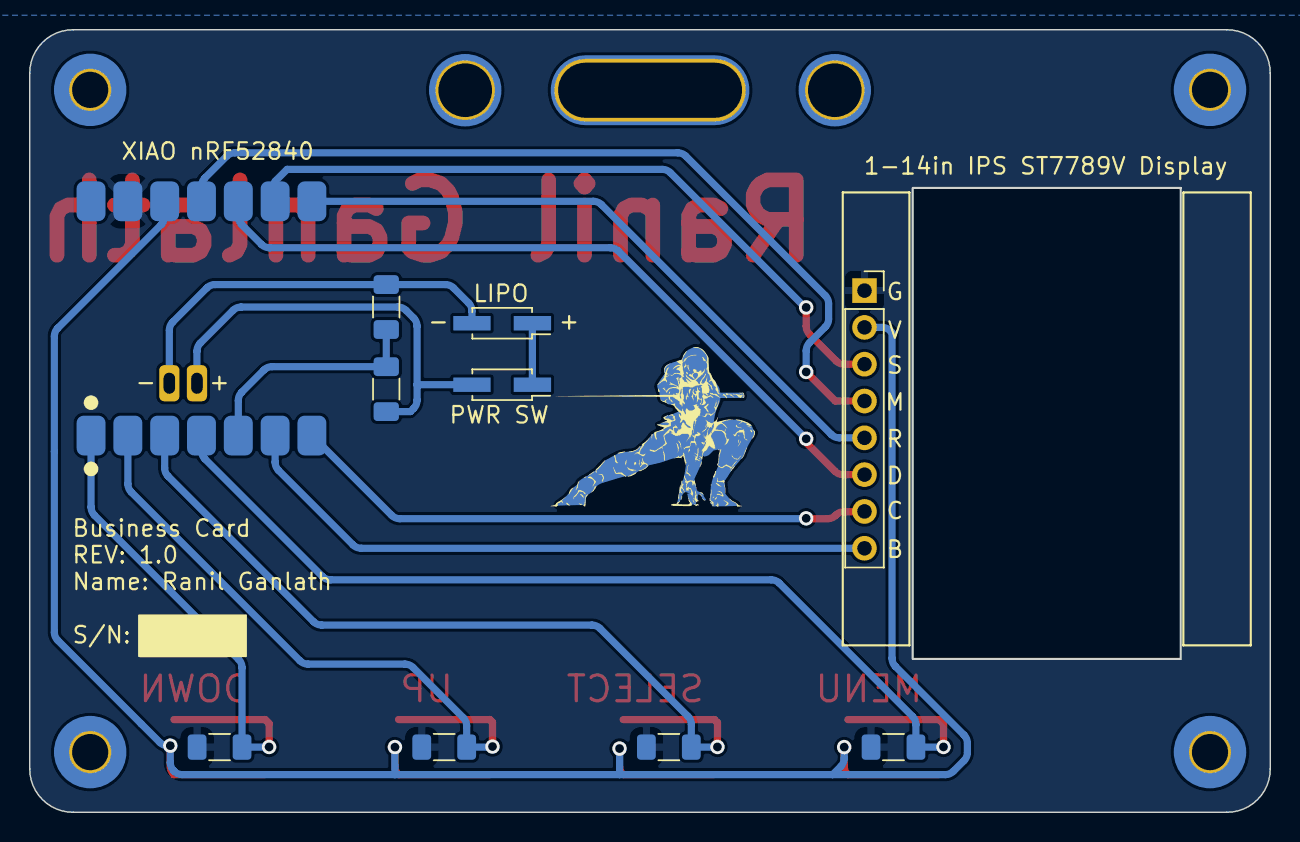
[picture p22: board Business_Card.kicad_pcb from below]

Board: 2 copper layers, 85.6 x 54.0 mm, 21 parts (13 on the bottom side), 16 nets.

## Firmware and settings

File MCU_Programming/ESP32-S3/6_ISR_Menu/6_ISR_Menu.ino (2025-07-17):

/*
  By Ranil Ganlath
  This is for testing bitmaps with menu with the IPS Display and the QT Py ESP32-S3 with No PSRAM.
  Modified to use interrupts for button handling.
  
  ESP32-S3 GPIO18 - Pushbutton, Down
  ESP32-S3 GPIO17 - Pushbutton, Up
  ESP32-S3 GPIO9 - Pushbutton, Select
  ESP32-S3 GPIO8 - Pushbutton, Menu/Back
  ESP32-S3 GPIO7 - Battery Sense, (4.3V = 2.96V, 2.8V = 1.93V) (Not wired)
  ESP32-S3 GPIO6 - TFT_BL, BLK (Backlight)
  ESP32-S3 GPIO5 - TFT_CS
  ESP32-S3 GPIO35 - TFT_MOSI
  ESP32-S3 GPIO37 - TFT_DC, DC (Data Command)
  ESP32-S3 GPIO36 - TFT_SCLK, SCL (CLK / SCK)
  ESP32-S3 GPIO16 - TFT_RST, RES (Reset)
  IPS Display Size: 135x240
  
  IDE Configuration:
  Make sure all the display driver and pin connections are correct by
  editing the User_Setup.h file in the TFT_eSPI library folder.
 #########################################################################
 ###### DON'T FORGET TO UPDATE THE User_Setup.h FILE IN THE LIBRARY ######
 #########################################################################
*/

#define downButton 18
#define upButton 17
#define selectButton 9
#define menuButton 8

//Define Codec Colors
#define ColorCodecMainText 0x97D9
#define ColorCodecCallText 0x21A6
#define ColorCodecCallTextSelected 0x6551
#define ColorCodecBG 0x0000
#define ColorCodecText 0xC617
#define ColorCodecTextNote 0x42EA

#include <TFT_eSPI.h>       // Hardware-specific library

//Add Bitmap Images
#include "CAMPBELL.h"
#include "CAMPBELLM.h"
#include "DEEPTHROAT.h"
#include "LIQUID.h"
#include "MEILING.h"
#include "MEILINGB.h"
#include "MEILINGM.h"
#include "MERYL.h"
#include "MERYLB.h"
#include "MERYLM.h"
#include "MILLER.h"
#include "MILLERM.h"
#include "NAOMI.h"
#include "NAOMIB.h"
#include "NAOMIM.h"
#include "NASTASHA.h"
#include "NASTASHAB.h"
#include "NASTASHAM.h"
#include "OTACON.h"
#include "OTACONB.h"
#include "OTACONM.h"
#include "SNAKE.h"
#include "SNAKEB.h"
#include "SNAKEM.h"
#include "SNIPERWOLF.h"
#include "SNIPERWOLFB.h"
#include "SNIPERWOLFM.h"
#include "Select.h"

TFT_eSPI tft = TFT_eSPI(135,240);  // Invoke custom library

// Menu structure definitions
struct MenuItem {
  String name;
  int subMenuCount;
  MenuItem* subMenus;
  bool isAction;
};

// Menu state variables
int currentMenuLevel = 0;
int currentSelection[5] = {0, 0, 0, 0, 0}; // Support up to 5 levels deep
MenuItem* currentMenu;
int maxMenuLevels = 5;

// Interrupt-based button handling variables
volatile bool menuButtonPressed = false;
volatile bool selectButtonPressed = false;
volatile bool upButtonPressed = false;
volatile bool downButtonPressed = false;

// Button debouncing variables for interrupts
volatile unsigned long lastMenuInterrupt = 0;
volatile unsigned long lastSelectInterrupt = 0;
volatile unsigned long lastUpInterrupt = 0;
volatile unsigned long lastDownInterrupt = 0;
const unsigned long debounceDelay = 200; // Increased for interrupt handling

// Display parameters
const int MENU_ITEM_HEIGHT = 25;
const int MENU_START_Y = 30;
const int MAX_VISIBLE_ITEMS = 7;
int scrollOffset = 0;

// Animation control variables
bool animationActive = false;
bool animationButtonPressed = false;

// Define submenu items
MenuItem callItems[] = {
  {"SNAKE", 0, nullptr, true},
  {"CAMPBELL", 0, nullptr, true},
  {"NAOMI", 0, nullptr, true},
  {"MILLER", 0, nullptr, true},
  {"LIQUID", 0, nullptr, true},
  {"OTACON", 0, nullptr, true},
  {"SNIPER WOLF", 0, nullptr, true},
  {"MERYL", 0, nullptr, true},
  {"MEI LING", 0, nullptr, true},
  {"NASTASHA", 0, nullptr, true},
  {"DEEPTHROAT", 0, nullptr, true}
};

MenuItem animatedItems[] = {
  {"An SNAKE", 0, nullptr, true},
  {"An CAMPBELL", 0, nullptr, true},
  {"An NAOMI", 0, nullptr, true},
  {"An MILLER", 0, nullptr, true},
  {"An OTACON", 0, nullptr, true},
  {"An SNIPER WOLF", 0, nullptr, true},
  {"An MERYL", 0, nullptr, true},
  {"An MEI LING", 0, nullptr, true},
  {"An NASTASHA", 0, nullptr, true}
};

MenuItem settingsItems[] = {
  {"Brightness", 0, nullptr, true},
  {"Restart System", 0, nullptr, true},
};

MenuItem QRItems[] = {
  {"Business Card", 0, nullptr, true},
  {"LinkedIn", 0, nullptr, true},
  {"Github", 0, nullptr, true},
};

// Main menu items
MenuItem mainMenuItems[] = {
  {"Call", 11, callItems, false},
  {"Incoming Call", 0, nullptr, true},
  {"Animated", 9, animatedItems, false},
  {"Settings", 2, settingsItems, false},
  {"QR", 3, QRItems, false},  
  {"Games", 0, nullptr, true},
  {"Sleep", 0, nullptr, true}
};

// Root menu
MenuItem rootMenu = {"Main Menu", 7, mainMenuItems, false};

// Interrupt Service Routines (ISRs)
void IRAM_ATTR menuButtonISR() {
  unsigned long currentTime = millis();
  if (currentTime - lastMenuInterrupt > debounceDelay) {
    menuButtonPressed = true;
    lastMenuInterrupt = currentTime;
    if (animationActive) {
      animationButtonPressed = true;
    }
  }
}

void IRAM_ATTR selectButtonISR() {
  unsigned long currentTime = millis();
  if (currentTime - lastSelectInterrupt > debounceDelay) {
    selectButtonPressed = true;
    lastSelectInterrupt = currentTime;
    if (animationActive) {
      animationButtonPressed = true;
    }
  }
}

void IRAM_ATTR upButtonISR() {
  unsigned long currentTime = millis();
  if (currentTime - lastUpInterrupt > debounceDelay) {
    upButtonPressed = true;
    lastUpInterrupt = currentTime;
    if (animationActive) {
      animationButtonPressed = true;
    }
  }
}

void IRAM_ATTR downButtonISR() {
  unsigned long currentTime = millis();
  if (currentTime - lastDownInterrupt > debounceDelay) {
    downButtonPressed = true;
    lastDownInterrupt = currentTime;
    if (animationActive) {
      animationButtonPressed = true;
    }
  }
}

void setup() {
  Serial.begin(115200);
  
  // Initialize buttons (external pulldown resistors)
  pinMode(downButton, INPUT);
  pinMode(upButton, INPUT);
  pinMode(selectButton, INPUT);
  pinMode(menuButton, INPUT);
  
  // Attach interrupts (RISING edge since we're using external pull-down resistors)
  attachInterrupt(digitalPinToInterrupt(menuButton), menuButtonISR, RISING);
  attachInterrupt(digitalPinToInterrupt(selectButton), selectButtonISR, RISING);
  attachInterrupt(digitalPinToInterrupt(upButton), upButtonISR, RISING);
  attachInterrupt(digitalPinToInterrupt(downButton), downButtonISR, RISING);
  
  // Initialize display
  tft.begin();
  tft.setRotation(0);  // portrait
  tft.fillScreen(ColorCodecBG);
  tft.setSwapBytes(true);
  tft.setTextSize(1);
  tft.setTextColor(ColorCodecCallText);
  
  // Initialize menu system
  currentMenu = &rootMenu;
  currentMenuLevel = 0;
  
  // Draw initial menu
  drawMenu();
  
  delay(500);
}

void loop() {
  // Handle button presses from interrupts
  if (menuButtonPressed) {
    menuButtonPressed = false;
    handleMenuButton();
  }
  
  if (selectButtonPressed) {
    selectButtonPressed = false;
    handleSelectButton();
  }
  
  if (upButtonPressed) {
    upButtonPressed = false;
    handleUpButton();
  }
  
  if (downButtonPressed) {
    downButtonPressed = false;
    handleDownButton();
  }
  
  // Small delay to prevent overwhelming the system
  delay(10);
}

void drawMenu() {
  tft.fillScreen(ColorCodecBG); 
  // Draw title
  tft.setTextColor(ColorCodecMainText);
  tft.setTextSize(2);
  tft.setCursor(5, 5);
  tft.println(currentMenu->name);
  
  // Draw menu items
  tft.setTextSize(1);
  int itemCount = currentMenu->subMenuCount;
  
  // Calculate visible range
  int currentPos = currentSelection[currentMenuLevel];
  if (currentPos < scrollOffset) {
    scrollOffset = currentPos;
  }
  if (currentPos >= scrollOffset + MAX_VISIBLE_ITEMS) {
    scrollOffset = currentPos - MAX_VISIBLE_ITEMS + 1;
  }
  
  for (int i = 0; i < MAX_VISIBLE_ITEMS && (i + scrollOffset) < itemCount; i++) {
    int itemIndex = i + scrollOffset;
    int yPos = MENU_START_Y + (i * MENU_ITEM_HEIGHT);
    
    // Highlight selected item
    if (itemIndex == currentPos) {
      tft.setTextColor(ColorCodecCallTextSelected);
    } else {
      tft.setTextColor(ColorCodecCallText);
    }
    
    tft.setCursor(5, yPos);
    
    // Add indicator for submenus
    if (!currentMenu->subMenus[itemIndex].isAction) {
      tft.print("> ");
    } else {
      tft.print("  ");
    }
    
    tft.print(currentMenu->subMenus[itemIndex].name);
  }
  
  // Draw scroll indicators
  if (scrollOffset > 0) {
    tft.setTextColor(ColorCodecTextNote);
    tft.setCursor(120, MENU_START_Y);
    tft.print("^");
  }
  
  if (scrollOffset + MAX_VISIBLE_ITEMS < itemCount) {
    tft.setTextColor(ColorCodecTextNote);
    tft.setCursor(120, MENU_START_Y + (MAX_VISIBLE_ITEMS - 1) * MENU_ITEM_HEIGHT);
    tft.print("v");
  }
  
  // Draw navigation help
  tft.setTextColor(ColorCodecTextNote);
  tft.setTextSize(1);
  tft.setCursor(5, 220);
  tft.print("Menu:Back Select:OK");
}

void handleMenuButton() {
  // Go back to previous menu level
  if (currentMenuLevel > 0) {
    currentMenuLevel--;
    currentSelection[currentMenuLevel + 1] = 0; // Reset submenu selection
    scrollOffset = 0;
    
    // Navigate back to parent menu
    currentMenu = &rootMenu;
    for (int i = 0; i < currentMenuLevel; i++) {
      currentMenu = &currentMenu->subMenus[currentSelection[i]];
    }
    
    drawMenu();
  }
}

void handleSelectButton() {
  int currentPos = currentSelection[currentMenuLevel];
  MenuItem* selectedItem = &currentMenu->subMenus[currentPos];
  
  if (selectedItem->isAction) {
    // Execute action
    executeAction(selectedItem->name);
  } else {
    // Navigate to submenu
    if (currentMenuLevel < maxMenuLevels - 1) {
      currentMenuLevel++;
      currentSelection[currentMenuLevel] = 0;
      scrollOffset = 0;
      currentMenu = selectedItem;
      drawMenu();
    }
  }
}

void handleUpButton() {
  if (currentSelection[currentMenuLevel] > 0) {
    currentSelection[currentMenuLevel]--;
    drawMenu();
  }
}

void handleDownButton() {
  if (currentSelection[currentMenuLevel] < currentMenu->subMenuCount - 1) {
    currentSelection[currentMenuLevel]++;
    drawMenu();
  }
}

void animationSNAKE(){
    // Animated Snake with interrupt-based exit
    animationActive = true;
    animationButtonPressed = false;
    tft.pushImage(0,0,140,240,SNAKE);
    while (!animationButtonPressed) {
      int randomNumber = random(11);
      if(randomNumber>4){//make them talk
        delay(random(300,500));
        tft.pushImage(32,127,86,59,SNAKEM);
        delay(random(300,500));
        tft.pushImage(0,0,140,240,SNAKE);
        if(randomNumber>6){
          delay(random(300,500));
          tft.pushImage(32,127,86,59,SNAKEM);
          delay(random(300,500));
          tft.pushImage(0,0,140,240,SNAKE);
          if(randomNumber>7){
            delay(random(300,500));
            tft.pushImage(32,127,86,59,SNAKEM);
            delay(random(300,500));
            tft.pushImage(0,0,140,240,SNAKE);
          }
          if(randomNumber>8){
            tft.pushImage(11,73,118,35,SNAKEB);
            delay(random(400,600));
            tft.pushImage(0,0,140,240,SNAKE);
          }
        }
      }
      if (animationButtonPressed) break;
      delay(random(400,3000));
      if (animationButtonPressed) break;
    }
    animationActive = false;
    animationButtonPressed = false;
}

void animationCAMPBELL(){
    // Animated Campbell with interrupt-based exit
    animationActive = true;
    animationButtonPressed = false;
    tft.pushImage(0,0,140,240,CAMPBELL);
    while (!animationButtonPressed) {
      int randomNumber = random(11);
      if(randomNumber>4){//make them talk
        delay(random(300,500));
        tft.pushImage(27,92,91,91,CAMPBELLM);
        delay(random(300,500));
        tft.pushImage(0,0,140,240,CAMPBELL);
        if(randomNumber>6){
          delay(random(300,500));
          tft.pushImage(27,92,91,91,CAMPBELLM);
          delay(random(300,500));
          tft.pushImage(0,0,140,240,CAMPBELL);
          if(randomNumber>8){
            delay(random(300,500));
            tft.pushImage(27,92,91,91,CAMPBELLM);
            delay(random(300,500));
            tft.pushImage(0,0,140,240,CAMPBELL);
          }
        }
      }
      if (animationButtonPressed) break;
      delay(random(400,3000));
      if (animationButtonPressed) break;
    }
    animationActive = false;
    animationButtonPressed = false;
}

void animationNAOMI(){
    // Animated Naomi with interrupt-based exit
    animationActive = true;
    animationButtonPressed = false;
    tft.pushImage(0,0,140,240,NAOMI);
    while (!animationButtonPressed) {
      int randomNumber = random(11);
      if(randomNumber>4){//make them talk
        delay(random(300,500));
        tft.pushImage(32,132,70,37,NAOMIM);
        delay(random(300,500));
        tft.pushImage(0,0,140,240,NAOMI);
        if(randomNumber>6){
          delay(random(300,500));
          tft.pushImage(32,132,70,37,NAOMIM);
          delay(random(300,500));
          tft.pushImage(0,0,140,240,NAOMI);
          if(randomNumber>7){
            delay(random(300,500));
            tft.pushImage(32,132,70,37,NAOMIM);
            delay(random(300,500));
            tft.pushImage(0,0,140,240,NAOMI);
          }
          if(randomNumber>8){
            tft.pushImage(11,79,113,32,NAOMIB);
            delay(random(400,600));
            tft.pushImage(0,0,140,240,NAOMI);
          }
        }
      }
      if (animationButtonPressed) break;
      delay(random(400,3000));
      if (animationButtonPressed) break;
    }
    animationActive = false;
    animationButtonPressed = false;
}

void animationMILLER(){
    // Animated Miller with interrupt-based exit
    animationActive = true;
    animationButtonPressed = false;
    tft.pushImage(0,0,140,240,MILLER);
    while (!animationButtonPressed) {
      int randomNumber = random(11);
      if(randomNumber>4){//make them talk
        delay(random(300,500));
        tft.pushImage(32,121,81,43,MILLERM);
        delay(random(300,500));
        tft.pushImage(0,0,140,240,MILLER);
        if(randomNumber>6){
          delay(random(300,500));
          tft.pushImage(32,121,81,43,MILLERM);
          delay(random(300,500));
          tft.pushImage(0,0,140,240,MILLER);
          if(randomNumber>8){
            delay(random(300,500));
            tft.pushImage(32,121,81,43,MILLERM);
            delay(random(300,500));
            tft.pushImage(0,0,140,240,MILLER);
          }
        }
      }
      if (animationButtonPressed) break;
      delay(random(400,3000));
      if (animationButtonPressed) break;
    }
    animationActive = false;
    animationButtonPressed = false;
}

void animationOTACON(){
    // Animated Otacon with interrupt-based exit
    animationActive = true;
    animationButtonPressed = false;
    tft.pushImage(0,0,140,240,OTACON);
    while (!animationButtonPressed) {
      int randomNumber = random(11);
      if(randomNumber>4){//make them talk
        delay(random(300,500));
        tft.pushImage(22,135,86,48,OTACONM);
        delay(random(300,500));
        tft.pushImage(0,0,140,240,OTACON);
        if(randomNumber>6){
          delay(random(300,500));
          tft.pushImage(22,135,86,48,OTACONM);
          delay(random(300,500));
          tft.pushImage(0,0,140,240,OTACON);
          if(randomNumber>7){
            delay(random(300,500));
            tft.pushImage(22,135,86,48,OTACONM);
            delay(random(300,500));
            tft.pushImage(0,0,140,240,OTACON);
          }
          if(randomNumber>8){
            tft.pushImage(27,79,97,45,OTACONB);
            delay(random(400,600));
            tft.pushImage(0,0,140,240,OTACON);
          }
        }
      }
      if (animationButtonPressed) break;
      delay(random(400,3000));
      if (animationButtonPressed) break;
    }
    animationActive = false;
    animationButtonPressed = false;
}

void animationSNIPERWOLF(){
    // Animated Sniper Wolf with interrupt-based exit
    animationActive = true;
    animationButtonPressed = false;
    tft.pushImage(0,0,140,240,SNIPERWOLF);
    while (!animationButtonPressed) {
      int randomNumber = random(11);
      if(randomNumber>4){//make them talk
        delay(random(300,500));
        tft.pushImage(38,129,64,35,SNIPERWOLFM);
        delay(random(300,500));
        tft.pushImage(0,0,140,240,SNIPERWOLF);
        if(randomNumber>6){
          delay(random(300,500));
          tft.pushImage(38,129,64,35,SNIPERWOLFM);
          delay(random(300,500));
          tft.pushImage(0,0,140,240,SNIPERWOLF);
          if(randomNumber>7){
            delay(random(300,500));
            tft.pushImage(38,129,64,35,SNIPERWOLFM);
            delay(random(300,500));
            tft.pushImage(0,0,140,240,SNIPERWOLF);
          }
          if(randomNumber>8){
            tft.pushImage(11,78,118,27,SNIPERWOLFB);
            delay(random(400,600));
            tft.pushImage(0,0,140,240,SNIPERWOLF);
          }
        }
      }
      if (animationButtonPressed) break;
      delay(random(400,3000));
      if (animationButtonPressed) break;
    }
    animationActive = false;
    animationButtonPressed = false;
}

void animationMERYL(){
    // Animated Meryl with interrupt-based exit
    animationActive = true;
    animationButtonPressed = false;
    tft.pushImage(0,0,140,240,MERYL);
    while (!animationButtonPressed) {
      int randomNumber = random(11);
      if(randomNumber>4){//make them talk
        delay(random(300,500));
        tft.pushImage(37,118,70,40,MERYLM);
        delay(random(300,500));
        tft.pushImage(0,0,140,240,MERYL);
        if(randomNumber>6){
          delay(random(300,500));
          tft.pushImage(37,118,70,40,MERYLM);
          delay(random(300,500));
          tft.pushImage(0,0,140,240,MERYL);
          if(randomNumber>7){
            delay(random(300,500));
            tft.pushImage(37,118,70,40,MERYLM);
            delay(random(300,500));
            tft.pushImage(0,0,140,240,MERYL);
          }
          if(randomNumber>8){
            tft.pushImage(11,64,124,35,MERYLB);
            delay(random(400,600));
            tft.pushImage(0,0,140,240,MERYL);
          }
        }
      }
      if (animationButtonPressed) break;
      delay(random(400,3000));
      if (animationButtonPressed) break;
    }
    animationActive = false;
    animationButtonPressed = false;
}

void animationMEILING(){
    // Animated Mei Ling with interrupt-based exit
    animationActive = true;
    animationButtonPressed = false;
    tft.pushImage(0,0,140,240,MEILING);
    while (!animationButtonPressed) {
      int randomNumber = random(11);
      if(randomNumber>4){//make them talk
        delay(random(300,500));
        tft.pushImage(38,138,64,37,MEILINGM);
        delay(random(300,500));
        tft.pushImage(0,0,140,240,MEILING);
        if(randomNumber>6){
          delay(random(300,500));
          tft.pushImage(38,138,64,37,MEILINGM);
          delay(random(300,500));
          tft.pushImage(0,0,140,240,MEILING);
          if(randomNumber>7){
            delay(random(300,500));
            tft.pushImage(38,138,64,37,MEILINGM);
            delay(random(300,500));
            tft.pushImage(0,0,140,240,MEILING);
          }
          if(randomNumber>8){
            tft.pushImage(11,89,118,37,MEILINGB);
            delay(random(400,600));
            tft.pushImage(0,0,140,240,MEILING);
          }
        }
      }
      if (animationButtonPressed) break;
      delay(random(400,3000));
      if (animationButtonPressed) break;
    }
    animationActive = false;
    animationButtonPressed = false;
}

void animationNASTASHA(){
    // Animated Nastasha with interrupt-based exit
    animationActive = true;
    animationButtonPressed = false;
    tft.pushImage(0,0,140,240,NASTASHA);
    while (!animationButtonPressed) {
      int randomNumber = random(11);
      if(randomNumber>4){//make them talk
        delay(random(300,500));
        tft.pushImage(16,138,113,62,NASTASHAM);
        delay(random(300,500));
        tft.pushImage(0,0,140,240,NASTASHA);
        if(randomNumber>6){
          delay(random(300,500));
          tft.pushImage(16,138,113,62,NASTASHAM);
          delay(random(300,500));
          tft.pushImage(0,0,140,240,NASTASHA);
          if(randomNumber>7){
            delay(random(300,500));
            tft.pushImage(16,138,113,62,NASTASHAM);
            delay(random(300,500));
            tft.pushImage(0,0,140,240,NASTASHA);
          }
          if(randomNumber>8){
            tft.pushImage(16,86,113,35,NASTASHAB);
            delay(random(400,600));
            tft.pushImage(0,0,140,240,NASTASHA);
          }
        }
      }
      if (animationButtonPressed) break;
      delay(random(400,3000));
      if (animationButtonPressed) break;
    }
    animationActive = false;
    animationButtonPressed = false;
}

void incomingCall(){
    tft.fillScreen(TFT_BLACK);
    delay(800);
    tft.pushImage(0,116,135,38,Select);
    delay(800);
    tft.fillScreen(TFT_BLACK);
    delay(800);
    tft.pushImage(0,116,135,38,Select);
    delay(800);
    tft.fillScreen(TFT_BLACK);
    delay(1100);
    tft.pushImage(0,116,135,38,Select);
    delay(800);
    tft.fillScreen(TFT_BLACK);
    delay(800);
    tft.pushImage(0,116,135,38,Select);
}
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

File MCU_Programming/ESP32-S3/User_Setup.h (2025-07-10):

//                            USER DEFINED SETTINGS
//   Set driver type, fonts to be loaded, pins used and SPI control method etc.
//
//   See the User_Setup_Select.h file if you wish to be able to define multiple
//   setups and then easily select which setup file is used by the compiler.
//
//   If this file is edited correctly then all the library example sketches should
//   run without the need to make any more changes for a particular hardware setup!
//   Note that some sketches are designed for a particular TFT pixel width/height

// User defined information reported by "Read_User_Setup" test & diagnostics example
#define USER_SETUP_INFO "User_Setup"
#define USE_HSPI_PORT

// Define to disable all #warnings in library (can be put in User_Setup_Select.h)
//#define DISABLE_ALL_LIBRARY_WARNINGS

// ##################################################################################
//
// Section 1. Call up the right driver file and any options for it
//
// ##################################################################################

// Define STM32 to invoke optimised processor support (only for STM32)
//#define STM32

// Defining the STM32 board allows the library to optimise the performance
// for UNO compatible "MCUfriend" style shields
//#define NUCLEO_64_TFT
//#define NUCLEO_144_TFT

// STM32 8-bit parallel only:
// If STN32 Port A or B pins 0-7 are used for 8-bit parallel data bus bits 0-7
// then this will improve rendering performance by a factor of ~8x
//#define STM_PORTA_DATA_BUS
//#define STM_PORTB_DATA_BUS

// Tell the library to use parallel mode (otherwise SPI is assumed)
//#define TFT_PARALLEL_8_BIT
//#defined TFT_PARALLEL_16_BIT // **** 16-bit parallel ONLY for RP2040 processor ****

// Display type -  only define if RPi display
//#define RPI_DISPLAY_TYPE // 20MHz maximum SPI

// Only define one driver, the other ones must be commented out
//#define ILI9341_DRIVER       // Generic driver for common displays
//#define ILI9341_2_DRIVER     // Alternative ILI9341 driver, see https://github.com/Bodmer/TFT_eSPI/issues/1172
//#define ST7735_DRIVER      // Define additional parameters below for this display
//#define ILI9163_DRIVER     // Define additional parameters below for this display
//#define S6D02A1_DRIVER
//#define RPI_ILI9486_DRIVER // 20MHz maximum SPI
//#define HX8357D_DRIVER
//#define ILI9481_DRIVER
//#define ILI9486_DRIVER
//#define ILI9488_DRIVER     // WARNING: Do not connect ILI9488 display SDO to MISO if other devices share the SPI bus (TFT SDO does NOT tristate when CS is high)
#define ST7789_DRIVER      // Full configuration option, define additional parameters below for this display
//#define ST7789_2_DRIVER    // Minimal configuration option, define additional parameters below for this display
//#define R61581_DRIVER
//#define RM68140_DRIVER
//#define ST7796_DRIVER
//#define SSD1351_DRIVER
//#define SSD1963_480_DRIVER
//#define SSD1963_800_DRIVER
//#define SSD1963_800ALT_DRIVER
//#define ILI9225_DRIVER
//#define GC9A01_DRIVER

// Some displays support SPI reads via the MISO pin, other displays have a single
// bi-directional SDA pin and the library will try to read this via the MOSI line.
// To use the SDA line for reading data from the TFT uncomment the following line:

// #define TFT_SDA_READ      // This option is for ESP32 ONLY, tested with ST7789 and GC9A01 display only

// For ST7735, ST7789 and ILI9341 ONLY, define the colour order IF the blue and red are swapped on your display
// Try ONE option at a time to find the correct colour order for your display

//#define TFT_RGB_ORDER TFT_RGB  // Colour order Red-Green-Blue
#define TFT_RGB_ORDER TFT_BGR  // Colour order Blue-Green-Red

// For M5Stack ESP32 module with integrated ILI9341 display ONLY, remove // in line below

// #define M5STACK

// For ST7789, ST7735, ILI9163 and GC9A01 ONLY, define the pixel width and height in portrait orientation
// #define TFT_WIDTH  80
#define TFT_WIDTH  135
// #define TFT_WIDTH  172 // ST7789 172 x 320
// #define TFT_WIDTH  170 // ST7789 170 x 320
// #define TFT_WIDTH  240 // ST7789 240 x 240 and 240 x 320
// #define TFT_HEIGHT 160
// #define TFT_HEIGHT 128
#define TFT_HEIGHT 240 // ST7789 240 x 240
// #define TFT_HEIGHT 320 // ST7789 240 x 320
// #define TFT_HEIGHT 240 // GC9A01 240 x 240

// For ST7735 ONLY, define the type of display, originally this was based on the
// colour of the tab on the screen protector film but this is not always true, so try
// out the different options below if the screen does not display graphics correctly,
// e.g. colours wrong, mirror images, or stray pixels at the edges.
// Comment out ALL BUT ONE of these options for a ST7735 display driver, save this
// this User_Setup file, then rebuild and upload the sketch to the board again:

// #define ST7735_INITB
// #define ST7735_GREENTAB
// #define ST7735_GREENTAB2
// #define ST7735_GREENTAB3
// #define ST7735_GREENTAB128    // For 128 x 128 display
// #define ST7735_GREENTAB160x80 // For 160 x 80 display (BGR, inverted, 26 offset)
// #define ST7735_ROBOTLCD       // For some RobotLCD Arduino shields (128x160, BGR, https://docs.arduino.cc/retired/getting-started-guides/TFT)
// #define ST7735_REDTAB
// #define ST7735_BLACKTAB
// #define ST7735_REDTAB160x80   // For 160 x 80 display with 24 pixel offset

// If colours are inverted (white shows as black) then uncomment one of the next
// 2 lines try both options, one of the options should correct the inversion.

#define TFT_INVERSION_ON
//#define TFT_INVERSION_OFF


// ##################################################################################
//
// Section 2. Define the pins that are used to interface with the display here
//
// ##################################################################################

// If a backlight control signal is available then define the TFT_BL pin in Section 2
// below. The backlight will be turned ON when tft.begin() is called, but the library
// needs to know if the LEDs are ON with the pin HIGH or LOW. If the LEDs are to be
// driven with a PWM signal or turned OFF/ON then this must be handled by the user
// sketch. e.g. with digitalWrite(TFT_BL, LOW);

// #define TFT_BL   32            // LED back-light control pin
// #define TFT_BACKLIGHT_ON HIGH  // Level to turn ON back-light (HIGH or LOW)
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

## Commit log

2025-06-12 Initial Project Files
    [Business_Card.kicad_pcb, Business_Card.kicad_sch, XIAO-nRF52840 v15.step]
2025-06-13 PCB Schematic and Layout Updates
    [Business_Card.kicad_pcb, Business_Card.kicad_sch, ER-TFTM1.14-1 revised.step]
2025-06-18 PCB Revisions
    [Business_Card.kicad_pcb, Business_Card.kicad_sch]
2025-07-10 Code migrated from XIAO Sense to ESP32-S3 board.
2025-07-17 Enclosure Updates
2025-07-17 Core programming
    Rehauled code to work with ESP32-S3 XIAO compatible board

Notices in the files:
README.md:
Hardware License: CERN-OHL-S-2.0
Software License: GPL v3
